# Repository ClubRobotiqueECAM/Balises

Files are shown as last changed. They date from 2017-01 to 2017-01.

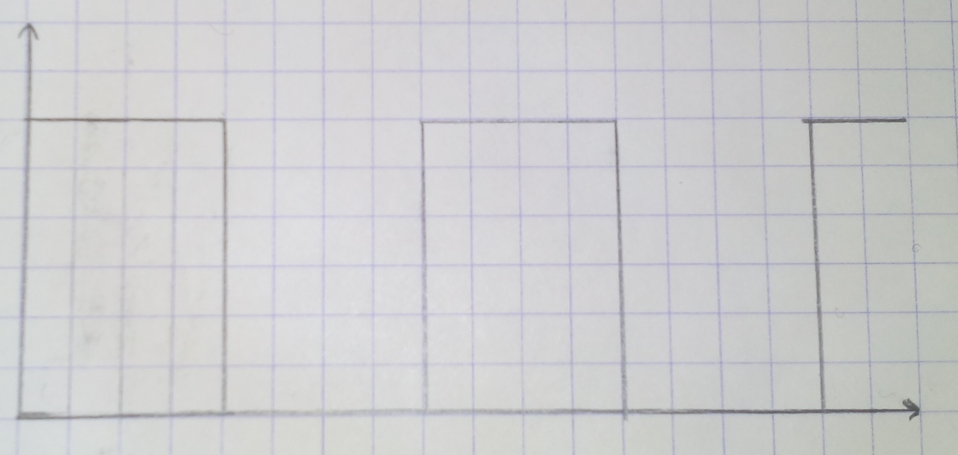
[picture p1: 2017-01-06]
Rapport/Fichiers supports/2015-11-20 09.31.01 mot.jpg

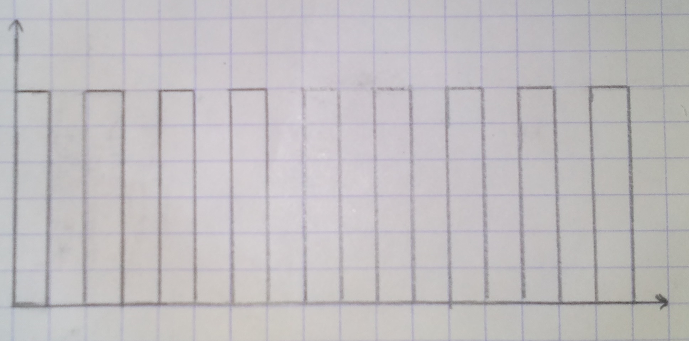
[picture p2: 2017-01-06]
Rapport/Fichiers supports/2015-11-20 09.34.17 porteuse.jpg

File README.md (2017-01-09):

#Balises de positionnement
===========

Projet de recherche et developpement de ma dernière année de l'ECAM. Ce projet est demandé par le club robotique afin de participer à la coupe de france de robotique.

##En résumé :

Le systeme est conposé de 3 balises fixes et d'une balise mobile à positionnée. Avec deux ondes de differentes célérité (Radio fréquence à 2.4GHz et ultrason à 40KHz) nous mesurons la difference de temps pour remonter a la distance.

##Contributing

  * Fork it
  * Create your feature branch (git checkout -b my-new-feature)
  * Commit your changes (git commit -am 'Add some feature')
  * Push to the branch (git push origin my-new-feature)
  * Create new Pull Request

Pour plus d'information rendez-vous dans le dossier "Rapport"

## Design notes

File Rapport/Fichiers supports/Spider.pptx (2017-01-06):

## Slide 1

Capteur
optique

Timer

Précision

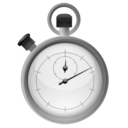
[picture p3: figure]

Durée

Composants haute
qualité

Périodique

Localiser

Récepteur

Etalonnage capteur définitif

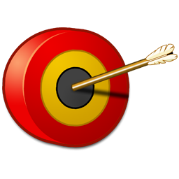
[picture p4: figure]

Distance

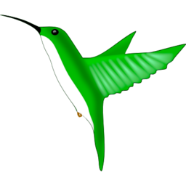
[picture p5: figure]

Pas d’obstacle physique

Pouvoir localiser sur toute la table

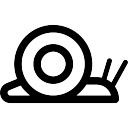
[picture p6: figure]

Calcul embarqué

Réactif

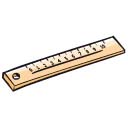
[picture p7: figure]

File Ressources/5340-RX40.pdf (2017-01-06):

# ULTRASONIC TRANSDUCER -RECEIVER

Order Code: MA40A5R

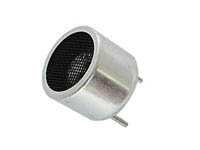
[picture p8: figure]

## Specifications

- description: ultrasonic transducer - receiver
- max. input voltage: 20Vrms
- operating temperature: -20°C to +85°C
- range: 0.2 to 6m
- nominal frequency: 40kHz
- sensitivity: -67dB min.
- sound pressure: 112dB min. •

## Dimensions

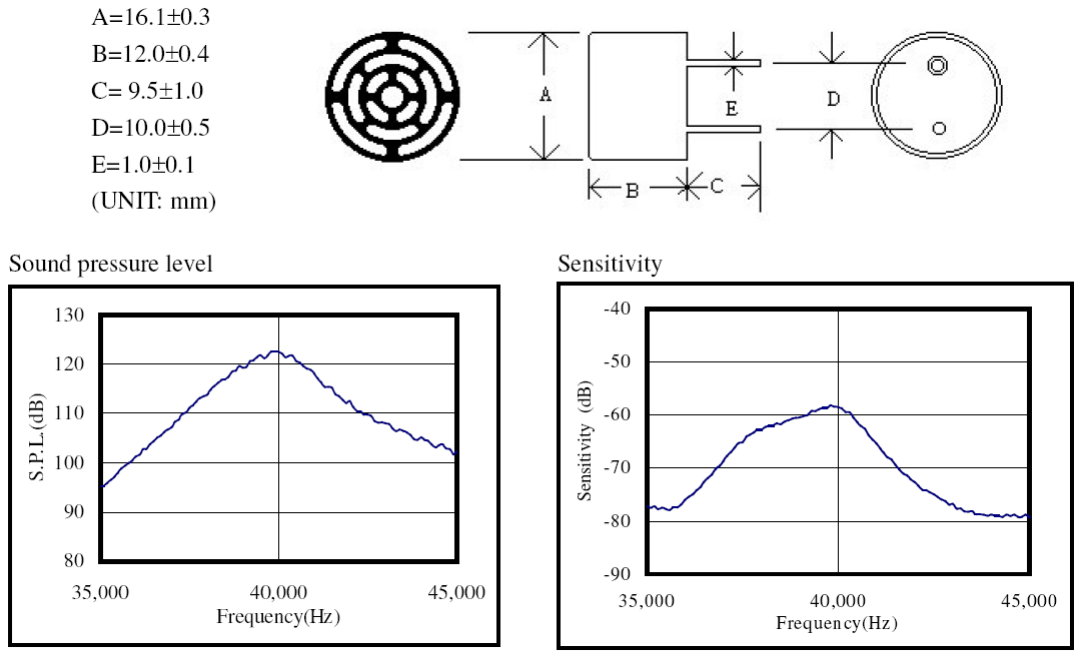
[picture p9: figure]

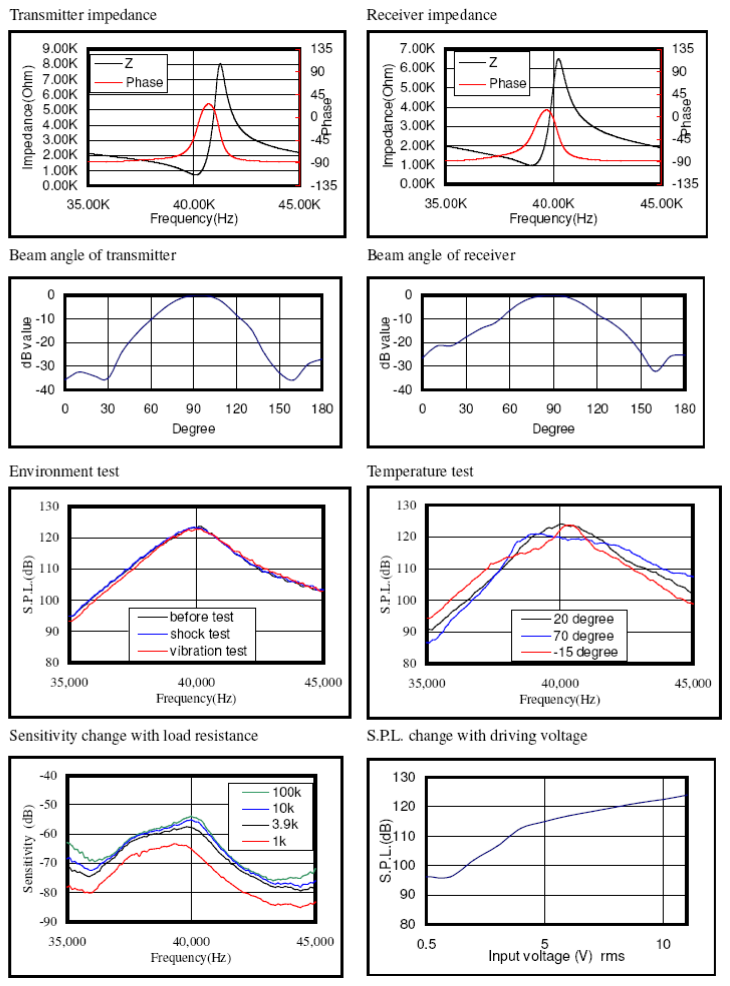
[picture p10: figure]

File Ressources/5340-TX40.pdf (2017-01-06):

# ULTRASONIC TRANSDUCER -TRANSMITTER

Order Code: MA40A5S


## Specifications

- description: ultrasonic transducer - transmitter
- max. input voltage: 20Vrms
- operating temperature: -20°C to +85°C
- range: 0.2 to 6m
- nominal frequency: 40kHz
- sensitivity: -67dB min.
- sound pressure: 112dB min.

## Dimensions

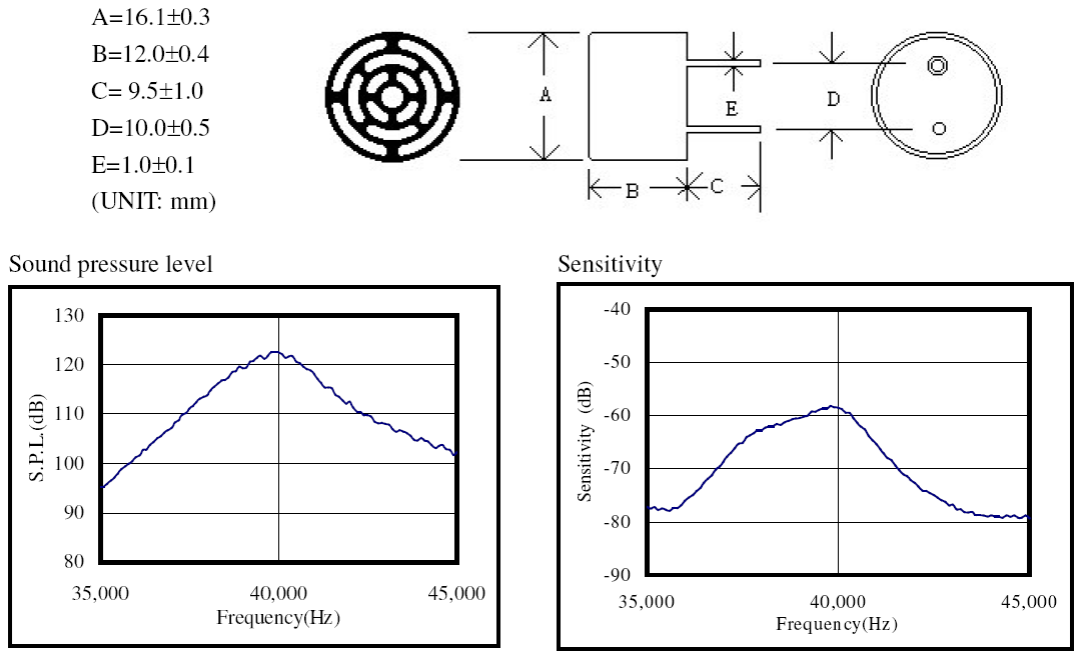
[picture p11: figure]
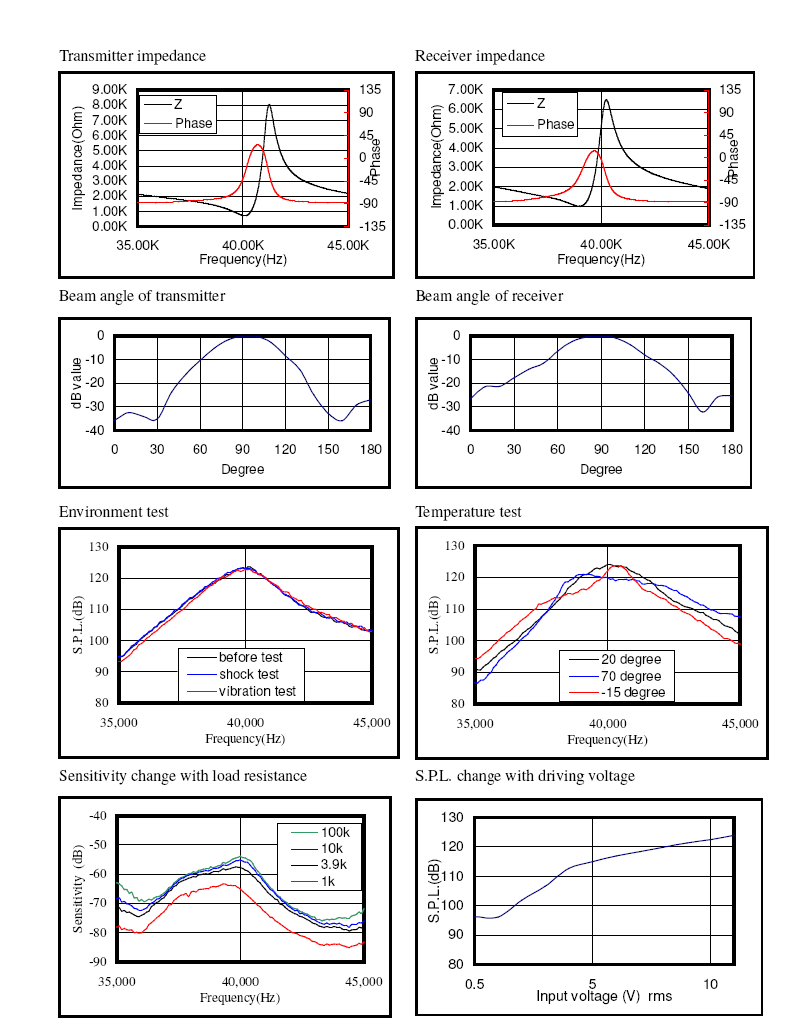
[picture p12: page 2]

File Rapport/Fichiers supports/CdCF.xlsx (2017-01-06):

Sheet: Feuil1
Cahier des charges
Numéro | Fonction | Critères | Niveau | Fléxibilité | check
1 | Permettre aux robots de se localiser sur la table | Ecart en x | +/- 5 cm |  | 1/2
 |  | Ecart en y | +/- 5 cm |  | 1/2
 |  | Fréquence de localisation | 1s |  | 1/2
2 | Fonctionner depuis emplacement présus sur les robots | Nbr de possibilité | 2 (alliée/adverse) |  | 1/0
 |  | Portée réception | 3m
3 | Se Fixer sur les emplacements prévus sur les robots | Type de fixation | amovible |  | 1/0
4 | Fonctionner depuis emplacement présus sur la table | Nbr de possibilité | 1 (3 positions fixes) |  | 2/0
 |  | Portée émission | 3m
5 | Se Fixer sur les emplacements prévus sur la table | Type de fixation | amovible |  | 2/0
6 | Respecter les dimensions imposées (lxLxh) | mobile | 80x80x80 mm |  | 3/0
 |  | fixe | 80x80x160mm |  | 3/0
7 | Respecter le poids imposé | mobile | 400g |  | 3/0
 |  | fixe | 400g |  | 3/0
8 | Ne pas êtres gêné par les perturbations | lumineuse |  |  | 4/0
 |  | sonore |  |  | 4/0
9 | Ne pas êtres perturbé par les balises adverses |  |  |  | 5/0
10 | Ne pas perturber les balises adverses |  |  |  | 0/5
11 | Etres réutilisable | durée de vie | 3 ans min. |  | 6/0
12 | Pouvoir choisir le nom de la balise | Mode de choix | plusieurs possibilité définis à l'avance |  | 7/0
13 | Pouvoir commender le démarrage | type de commande | Interrupteur manuel |  | 7/0
14 | Montrer le nom de la balise | type d'indicateur | visuel |  | 0/7
16 | Etres autonome | Type d'alimentation | battery |  | 0/0
 |  | autonomie | 15 minutes |  | 0/0

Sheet: Feuil2
Cahier des charges
Numéro | Fonction | Critères | Niveau | Fléxibilité | check
 | Localiser la balise mobile avec 3 fixes
 | Communiquer la position/mesure
 | Calculer la position
 | Respecter le volume maximal
 | Respecter le poids maximal
 | Positions imposées dans l'espace des 3 balises fixes
 | Etre auto-alimentée

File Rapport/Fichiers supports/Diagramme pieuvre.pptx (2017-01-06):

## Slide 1

Robots

Table

2

1

Règles de
la coupe

Balises
Autonomes

3

Utilisateur

0

Environnement extérieur

7

4

Club
robotique

Balises
ennemies

6

5

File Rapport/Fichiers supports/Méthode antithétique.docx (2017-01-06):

Méthode antithétique :

Perdre une balise

Cacher Obstacle (Visuel)

Invisible

Cacher parmi d’autre

Cacher dans l’environnement

Masquer son

Silence

Bruit

Pour localiser la balise :

- Visible/regarder
- Différentes des autres (se démarquer)
- Sans obstacle : règlement
- Son particulier / écoute

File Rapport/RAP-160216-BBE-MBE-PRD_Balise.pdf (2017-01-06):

# Balise de localisation pour Robot

## Projet de R&D

Pôle

Recherche et Développement

Auteurs | : Bruno BELLIER, Maxence BEROUJON
Date | : 16/02/2016
Promotion | : 2016

# Informations générales

Auteur(s)

Nom(s) | Bruno BELLIER, Maxence BEROUJON
Promotion | 2016
Formation | ECAM 5

Département

Nom | Pôle Recherche et Développement
Professeur référent | Christophe Jouve

# Sommaire

Introduction | 5
I. Cahier des charges | 6
II. La Créativité | 9
III. Tests et prototypages | 12
IV. Plan Balises | 14
1. | Le système des 4 balises | 15
2. | Principes généraux des balises fixes | 16
3. | Principes généraux de la balise fixe | 17
1. | Le circuit des balises fixes (émettrices US) | 18
1. | Le circuit de la balise mobile (réceptrice US) | 19
1. | Programme pour la balise mobile | 22
2. | Programme pour les balises fixe | 22

## Introduction

Dans le cadre de notre formation à l’ECAM Lyon, nous avons travaillé deux jours par semaine lors de notre dernier semestre de cours sur un Projet de Recherche et Développement. Ce dernier est particulier car il est financé et demandé par le Club robotique de l’ECAM.

Le binôme est constitué de Maxence Beroujon et Bruno Bellier. Pour nous aider les professeurs, le personnel et le matériel de l’ECAM ont été mis à notre disposition. Le Club robotique est une association d’élèves qui partagent la passion, ou qui veulent découvrir des connaissances en robotique. En mécanique de petit système, modélisation, électronique, et programmation. Depuis déjà 3 ans le club participe à la coupe de France de robotique. Cet évènement rassemble des étudiants qui ont la passion de la robotique, et il permet le challenge entre école. Le principe : 2 équipes s’affrontent sur la table. Elles ont pour but de faire le maximum de points. Chaque équipe est constituée de deux robots maximum.

Lors de cette coupe, les robots n’ont pas le droit d’être en contact. Et les robots doivent connaitre leur position pour faire des actions avec précision. C’est là que le projet intervient.

Grâce à nous les robots ECAM peuvent soit connaitre la position de l’adversaire, soit connaitre avec précision sa position.

Ce dossier retrace la démarche suivis lors du projet, c’est pourquoi il y a une évolution dans les choix technique au cours du dossier. Nous espérons que ce dossier vous sera utile pour comprendre ce qui nous a permis de faire nos choix, afin de modifier, améliorer, ou refaire les balises.

## I. Cahier des charges

## A. Cahier des charges initial

Afin de fixer des premières directions sur lesquelles s’engager, et de répondre aux exigences du club robotique de l’ECAM, nous avons élaboré un premier jet du cahier des charges, comprenant les fonctions principales du produit à réaliser. Ce document était principalement issu des règles de la coupe de France de robotique.

Le projet consiste donc à concevoir et réaliser un système de balises à placer sur le robot et sur le terrain de manière à pouvoir localiser le robot où qu’il soit sur la table.

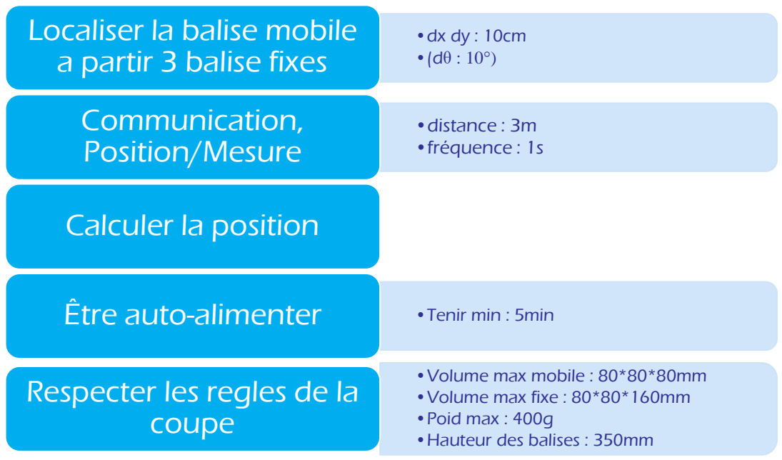
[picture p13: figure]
Localiser la balise mobile a partir 3 balise fixes; •distance : 3m •fréquence : 1s; Communication, Position/Mesure; Calculer la position; Être auto-alimenter; •Tenir min : 5min; •Volume max mobile : 80*80*80mm •Volume max fixe : 80*80*160mm •Poid max : 400g •Hauteur des balises : 350mm; Respecter les regles de la coupe

## B. Le diagramme pieuvre

Afin d’élaborer un cahier des charges complet et de s’approprier pleinement le sujet nous avons réalisé un diagramme pieuvre sur la phase de vie clé du produit qui est, dans notre cas, sa phase d’utilisation :

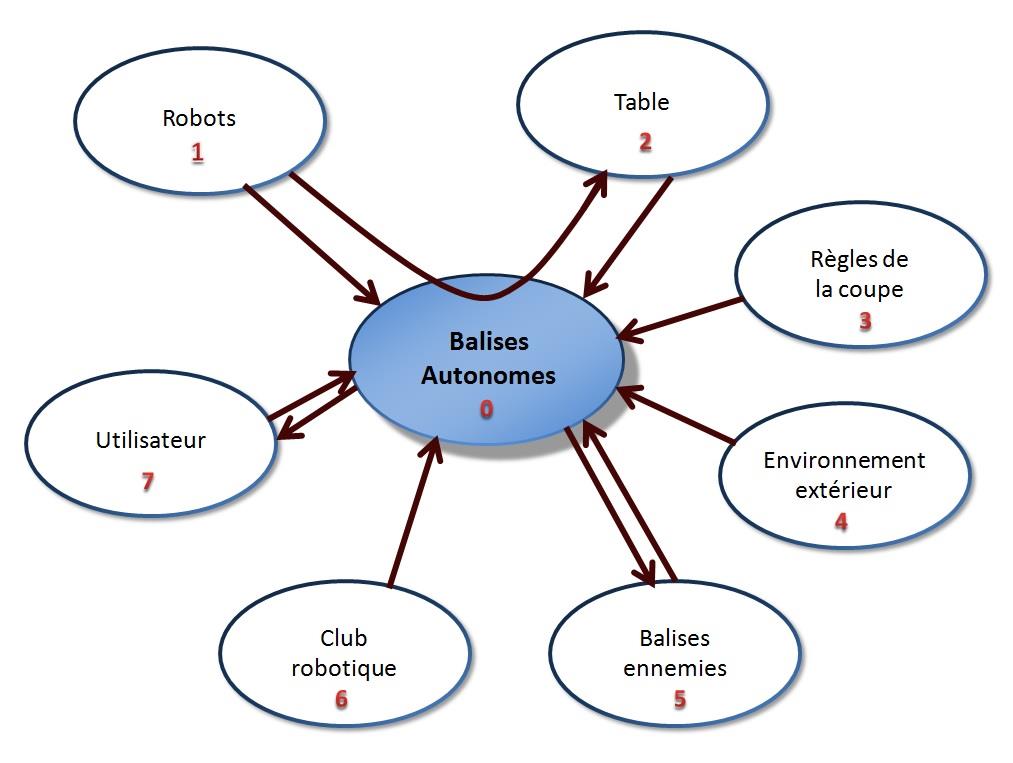
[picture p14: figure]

De ce diagramme pieuvre, on ressort différentes fonctions :

Fonction principale :

1→2 : Permettre aux robots de se localiser sur la table

Fonctions contraintes :

1→0 : - Fonctionner depuis emplacements prévus sur les robots
- Se fixer sur les emplacements prévus sur les robots

2→0 : - Fonctionner depuis emplacements prévus sur la table
- Se fixer sur les emplacements prévus sur la table

3→0 : - Respecter les dimensions imposées
- Respecter le poids imposé

4→0 : - Ne pas être gêné par les perturbations lumineuses (présentes lors de la compétition)
- Ne pas être gêné par les perturbations sonores (présentes lors de la compétition)

5→0 : - Ne pas être perturbé par les balises adverses

0→5 : - Ne pas perturber les balises adverses (volontairement)

6→0 : - Posséder une documentation complète et compréhensible de la partie programme
- Posséder une documentation complète et compréhensible de la partie physique
- Etres réutilisable et modifiable par le club dans l’avenir

7→0 : - Pouvoir choisir le nom de la balise
- Pouvoir commander le démarrage (même si l’alimentation est déjà faite)

0→7 : - Montrer à l’utilisateur le nom de la balise

0 : - Etre autonome en alimentation

## C. Cahier des charges fonctionnelles

Grâce aux outils précédents, nous avons pu réaliser un cahier des charges fonctionnelles auquel se référer durant le projet.
N° | Fonction | Critères | Niveau | Flexibilité | check
1 | Permettre aux robots de se localiser sur la table | Ecart en x | +/- 5 cm | | 1/2
| | Ecart en y | +/- 5 cm | | 1/2
| | Fréquence de localisation | 1s | | 1/2
2 | Fonctionner depuis emplacement prévus sur les robots | Nbr de possibilité | 2 (alliée/adverse) | | 1/0
| | Portée réception | 3m
3 | Se Fixer sur les emplacements prévus sur les robots | Type de fixation | amovible | | 1/0
4 | Fonctionner depuis emplacement prévus sur la table | Nbr de possibilité | 1 (3 positions fixes) | | 2/0
| | Portée émission | 3m
5 | Se Fixer sur les emplacements prévus sur la table | Type de fixation | amovible | | 2/0
6 | Respecter les dimensions imposées (lxLxh) | mobile | 80x80x80 mm | | 3/0
| | fixe | 80x80x160mm | | 3/0
7 | Respecter le poids imposé | mobile | 400g | | 3/0
| | fixe | 400g | | 3/0
8 | Ne pas être gêné par les perturbations | lumineuse | | | 4/0
| | sonore | | | 4/0
9 | Ne pas être perturbé par les balises adverses | | | | 5/0
10 | Ne pas perturber les balises adverses | | | | 0/5
11 | Etres réutilisable | durée de vie | 3 ans min. | | 6/0
12 | Pouvoir choisir le nom de la balise | Mode de choix | plusieurs possibilités définis à l'avance | | 7/0
13 | Pouvoir commander le démarrage | type de commande | Interrupteur manuel | | 7/0
14 | Montrer le nom de la balise | type d'indicateur | visuel | | 0/7
16 | Etres autonome | Type d'alimentation | batterie | | 0/0
| | autonomie | 15 minutes | | 0/0

## II. La Créativité

Une fois que nous avons déterminé les bases du projet, nous avons réfléchi aux différentes manières de répondre au cahier des charges. Pour cela nous avons réalisé une séance de créativité au cours de laquelle nous avons utilisé plusieurs méthodes.

## A. Réflexion antithétique

De manière à trouver des méthodes pour répondre aux fonctions, nous avons utilisé une réflexion antithétique. Cette méthode consiste à trouver toutes les manières de ne pas réaliser la fonction étudié afin de mettre en évidence tout ce qui est nécessaire et tout ce qui peut permettre de réaliser la fonction étudié.

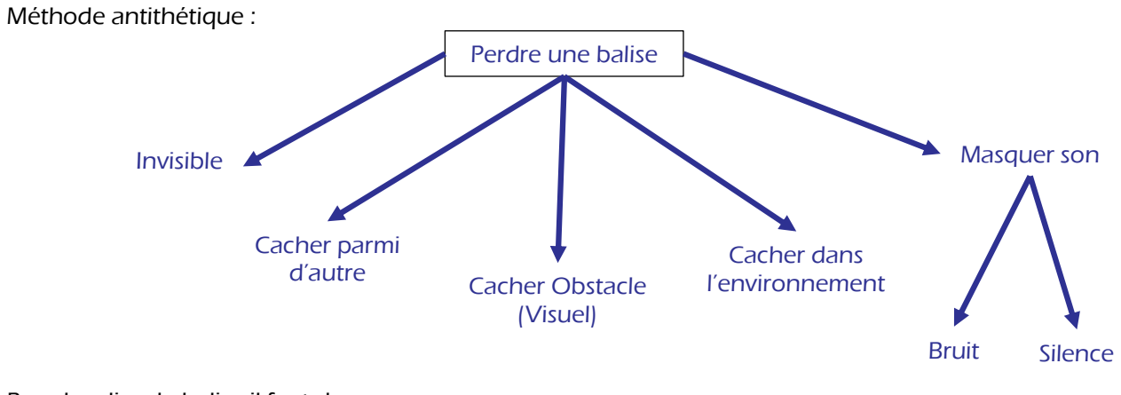
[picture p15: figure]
Méthode antithétique :; Perdre une balise; Cacher Obstacle (Visuel); Invisible; Cacher parmi d’autre; Cacher dans l’environnement; Masquer son; Bruit; Silence

Pour localiser la balise il faut donc:

- Etre visible/regarder
- Etre différentes des autres (se démarquer)
- Ne pas avoir d’obstacle : imposé par le règlement
- Emettre un son particulier / écouter

## B. Localiser un objet (Spider)

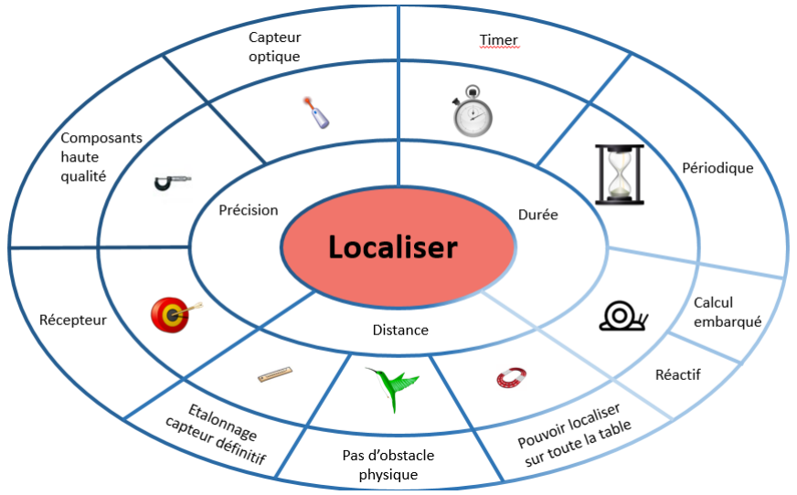
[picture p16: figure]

De ce spider, on ressort différente idées :

Le choix de capteur pour la réalisation de notre projet nous a semblé évident.

En, effet, les capteurs optiques nous semblaient être le moyen d’obtenir le plus de précision. Nous avons cependant étudié d’autres capteurs, comme les capteurs ultrasons, qui ne nous ont pas autant séduits.

Le règlement de la coupe de France de robotique impose les dimensions de la table, de ses décorations, ainsi que des robots, nous sommes donc assurés de ne pas avoir d’obstacle entre nos balises. Le robot se déplaçant sur l’intégralité de la table, nous devons pouvoir le localiser sur l’intégralité de la table.

Le robot étant en mouvement permanent, le système doit être réactif, la localisation doit donc s’effectuer rapidement. Nous avons décidé de faire l’ensemble des calculs de localisation dans la balise de réception (de manière embarqué), ainsi les seules informations transmises au robot sont ses coordonnées. Les mesures et calculs de localisation sont évidemment faits de manière périodique.

L’idée du timer (chronomètre) a été prise en compte dans notre solution par le fait que l’on utilise l’horloge interne de l’Arduino pour réaliser nos calculs.

Nous avons choisi d’effectuer un étalonnage des capteurs de façon définitive tant que l’on ne change pas d'environnement.

La volonté d’utiliser des composants de haute qualité n’a finalement pas été retenue afin de pouvoir épargner autant que possible le budget du club robot, donc d’avoir un budget PRD le plus faible possible tout en respectant nos critères de fonction.

## C. Calcul de position

Pour calculer la position du robot depuis les trois balises fixes, nous avons pensé à trois méthodes de calcul.

La première consiste à relever l’angle et la distance (couleur bleue et rouge figure1) entre chaque balise et le robot, pour avoir la position de ce dernier en coordonnées polaires. Ce qui nous amène à avoir une balise qui localise et deux balises qui vérifient cette localisation.

La deuxième consiste à mesurer seulement l’angle (en bleu) pour chaque balise. Mais après s’être renseigné un peu sur le sujet et y avoir réfléchi un certain temps. Nous nous sommes rendu compte que les mesures d’angle que l’on pouvait effectuer par cette méthode demeuraient très approximatives et ne permettaient donc pas d’obtenir la précision voulue.

Enfin, la troisième méthode permet de localiser le robot en mesurant les distances entre chaque balise et le robot. Cette méthode s’avère être la plus répandue et permet d’obtenir la plus grande précision quelle que soit la distance entre les balises et le robot. C’est finalement à partir de cette méthode de calculs, que nous avons basé notre réflexion.

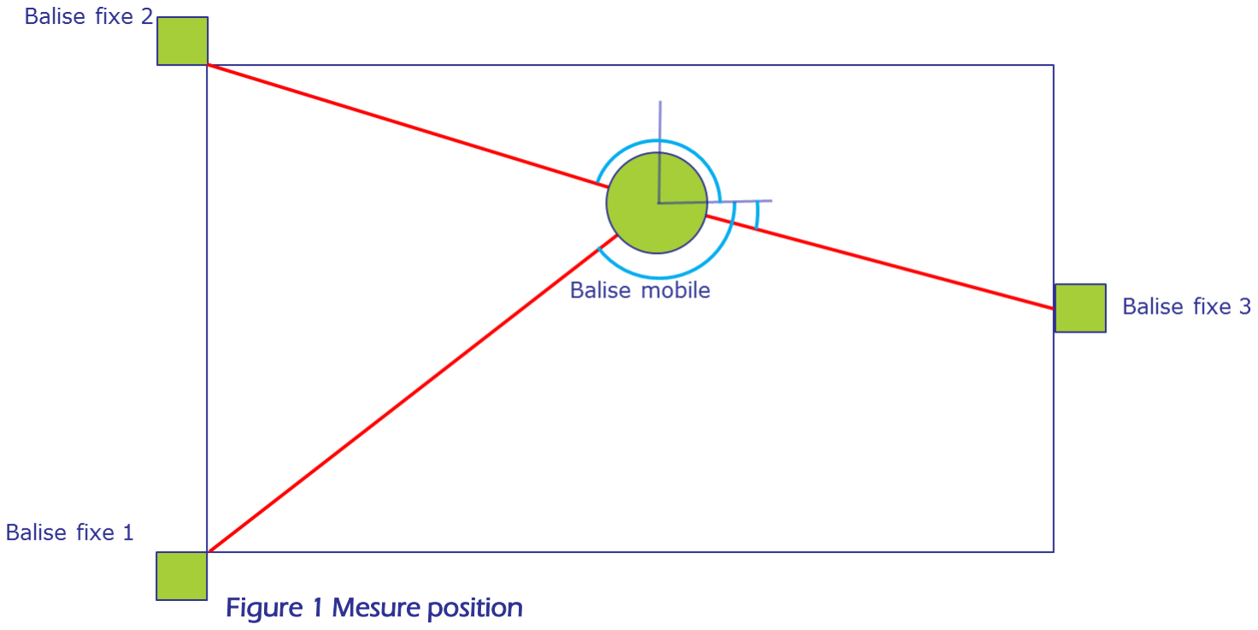
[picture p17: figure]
Figure 1 Mesure position

## D. Étude de 2 systèmes de mesure de distance existant

Après réflexion, nous nous sommes attardés sur deux types de capteurs afin d’effectuer nos mesures, à savoir, les capteurs infrarouges et les capteurs ultrasons.

Le capteur infrarouge possède une bonne plage de fréquence sur laquelle il est possible de travailler grâce à des émetteurs répartis sur cette plage. En revanche le champ d’action des capteurs est focalisé sur une seule direction avec un débattement de seulement 10° de chaque côté. De plus ils peuvent être rapidement perturbés par des sources lumineuses ou d’autres capteurs infrarouges. Or, lors de la coupe de France de robotique il existe beaucoup de perturbation de ce type. En effet, les spots émettent des infrarouges, et les balises adverses sont, d’après nos recherches, essentiellement basés sur un système infrarouge. Enfin, l’utilisation d’infrarouge est souvent employée pour des mesures d’angle (dans les cas de localisation par balises) et la localisation reste souvent très approximative.

L’ultrason travaille sur une plage de fréquence plus restreinte que l’infrarouge et les capteurs que nous avonstrouvés en vente ne travaillent que sur deux fréquences différentes 40 kHz ou 58kHz. En revanche, les capteurs permettent une diffusion plus large du signal (60° centré sur une direction). Les sources de perturbation sont la température et les autres sources d’ultrason. Cependant, la température ne fait varier que la vitesse de propagation des ultrasons, et dépend d’une formule. C’est donc une perturbation dont nous pouvons tenir compte dans les calculs. Par ailleurs, nous avons remarqué les ultrasons étaient très peu utilisés lors de la coupe de France de robotique. Enfin des résultats nous ont montrés que des mesures par ultrasons pouvait nous permettre d’être précis jusqu’au centimètre, ce qui nous permettrait de largement respecter le critère de précision de notre cahier des charges fonctionnel.

Au fait des résultats de ces recherches, nous avons décidé de baser notre projet sur l’utilisation des ultrasons.

## E. Analyse : sélection de HF+US

Tous les dispositifs que nous avons trouvés pour mesurer des distances à l’aide d’ultrasons étaient basés sur un principe d’aller-retour. Il est donc question d’une mesure de distance par rapport à un obstacle alors que nous souhaitions mesurer une distance par un barrage. Pour pouvoir effectuer une mesure directe entre deux points, nous avons alors utilisé une méthode permettant de s’affranchir de la fonction aller-retour classique. Ce principe sera peut-être à remettre en question dans les améliorations futures.

Cette méthode consiste à utiliser des ondes radios en guise de référence. Il s’agit d’émettre simultanément une onde HF (haute fréquence) et une onde US (ultrasonique). Les ondes HF sont des ondes « lumière » alors que les ondes US sont des ondes « son », ce qui modifie littéralement leur vitesse de propagation. Si on émet en même temps ces deux types d’ondes, les ondes HF arriveront bien plus vite que les ondes US. L’onde HF met 10ns pour parcourir 3m alors que les US met 8,8ms, on peut alors faire l’hypothèse que l’onde HF arrive instantanément et nous donne donc l’heure d’émission de l’onde US. Cette hypothèse engendre une erreur d’un nanomètre sur la mesure. Connaissant la vitesse et le temps entre l’émission et la réception, on peut alors trouver la distance entre l’émetteur et le récepteur.

Nous avons trouvé cette méthode ici. (http://em6.club.resel.fr/coupe_2003/coupe_2002/site%202001/anciens/balises1999.php3)

## III. Tests et prototypages

Cette partie survole nos étapes de prototypage. Cela vous servira d’exemple pour vos projets futurs, ou de contre-exemple. :D

## A. Emission continue

Pour la phase de conception électronique, nous avons trouvé la
datasheet | des | émetteurs | et | des
récepteurs que le club possède. Ce qui nous a donné un modèle, nous avons ensuite construit les circuitsfonction par fonction pour les tester au fur et à mesure. En premier lieu, le générateur de 40kHz en 0-10v puis la double amplitude centrée, -10v;10v pour le circuit émetteur.

Après nous avons construit le circuit de réception avec un aop en montage non-inverseur. Sur l'entrée +, il y a la
fonction | sommateur, | ainsi | qu'un
condensateur de lissage des pic. Le signal ce vois donc osciller, centrée sur le (5V).

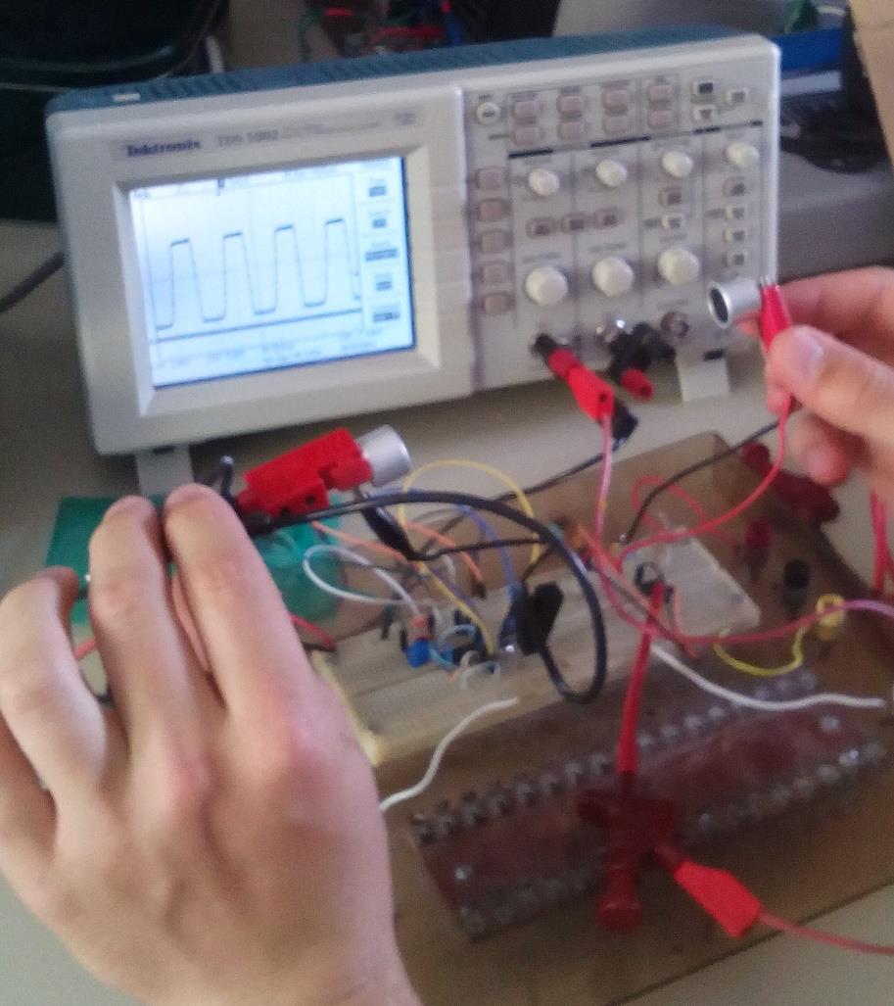
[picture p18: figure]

Avec les succès de ces deux parties, la liaison ultrason est assurée.

## B. Emission de 1110

Pour être sûr que les ultrasons captés proviennent bien de nos balises, des mots binaires sont insérés. Nous avons fait nos premiers tests avec un mot simple 1110.

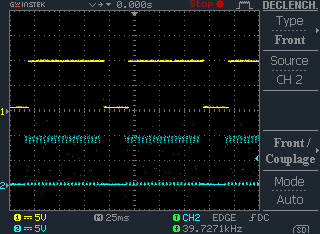
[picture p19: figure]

## C. Emission Serial puis Série de nous

Dans un premier temps nous avons utilisé le Sérial pour générer un mot, mais nous n’étions pas synchronisé, la réception n’arrivait pas à reconnaitre le début de la transmission. Nous avons opté pour la création d’un protocole de communication série unifilaire et unidirectionnel. Nous avons conservé ce mode de transmissions c’est pourquoi il sera développé ici.

## D. Emission HF

Grâce au projet léonard objet ludo-pédagogique, nous avons rapidement trouvé la référence, et la bibliothèque pour faire fonction la communication Haute fréquence. Avec une lecture approfondie des méthodes interne, nous remarquons que cette bibliothèque est faite pour une communication entre deux éléments. Le module quant à lui permet une réception en provenance de 5 adresses simultanément. Nous avons donc modifié la librairie.

## E. Emission HF+US

Une fois nos deux communications testées séparément, nous mettons en commun les programmes et les circuits pour former un prototype complet. Pour savoir si les communications fonctionnent correctement, la réception US attend un signal HF pour écoute les mots.

Avec un seul émetteur et un récepteur, nous avons obtenu de bons résultats à courte, moyenne et grande distances. Nous avons d’ailleurs fait une courbe pour voir si les résultats obtenu étaient une fonction simple de la distance ou pas. En l’occurrence, nous avons trouvé une fonction linéaire.

## F. Du prototypage à la réalisation

Pour des questions de cout et délai nous avons réalisé au club les cartes électroniques. Dans les différents dossiers

## IV. Plan Balises

Vous voici enfin dans la partie intéressante : Nous allons dévoiler tous les secrets des balises. Nous allons faire la présentation en pyramides : en premiers les concepts théorique, puis une vue d’ensemble, et enfin un détail technique le plus claire possible. Pour être sûr que vous vous rappelez de tout ce qui a été dit plus haut comme des solutions possible, nous n’avons pas hésitez à réécrire les éléments importants.

## A. Principes généraux

Les balises fonctionnent sur le principe du GPS : la mesure du temps de propagation à vitesse constante permet de déterminer une distance. Un GPS est à l’heure juste, dans la tram du signal il envoie l’heure d’émission et quand le GPS reçoit il calcul le temps puis la distance.

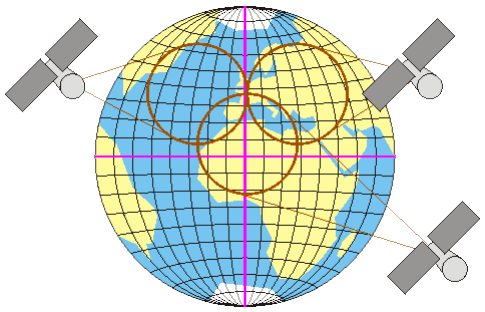
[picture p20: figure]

Sur une distance approximative de 20 000km à la vitesse de la lumière, le signal GPS met environ 66ms. Compte tenu de nos distance minuscules par rapport à celle mesurées par GPS nous avons opté pour l’émission d’onde ultrasonique US (8,8 ms pour 3m). Sauf que la célérité (c en m.s⁻¹
) du son est une
fonction de la température, θ en °C.

cair = (331.5 + 0.607 ∗ θ) m. s

−1

Cette approximation est valable sur des températures usuelles (-20 ; +40) avec une incertitude inférieure à 0.2%.

Pour la mesure du temps il faut une synchronisation. Dans le cas du GPS elle est faite au moment de l’envoie du satellite. C’est ici que nous avons besoin des ondes hautes fréquences HF (onde électromagnétique). (https://fr.wikipedia.org/wiki/Spectre_%C3%A9lectromagn%C3%A9tique) Ces dernières sont des ondes électromagnétique comme la lumière, et se propage à la même vitesse soit 299 792 458 m.s⁻¹
. Le temps de propagation de l’onde HF ajoute une erreur de 1µm sur la mesure donc nous négligeons de temps par rapport à la propagation de l’ultrason.

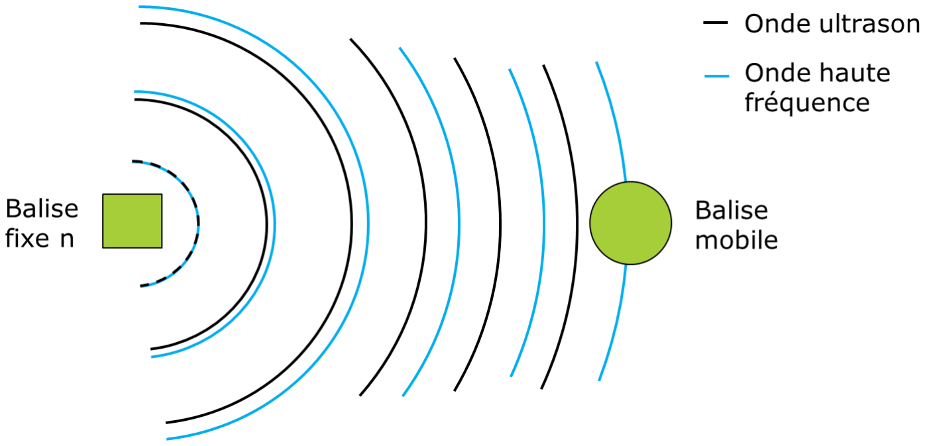
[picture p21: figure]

### 1. Le système des 4 balises

Pour se resituer, nous avons donc 4 balises, 1 de type Mobile, et 3 du type Fixe. Nous cherchons la position de la Mobile par rapport au 3 fixes.

a) Mesure et Calculs

Pour mesurer la distance, nous relevons l’heure d’arrivée du message HF, puis l’heure de réception du « start » du message US. On divise ensuite la durée, la différence entre les deux heures d’arrivée, par la vitesse du son afin d’obtenir la distance

Pour ensuite calculer les coordonnées de la balise mobile, on a obtenu une formule en partant du système suivant :{

d1

2 = (0 − x)
2 + (0 − y)

2
d2

2 = (0 − x)
2 + (200 −y)

2
d3

2 = (300 − x)
2 + (100 −y)

2

Où d1, d2 et d3 sont respectivement les distances mesurées avec la balise fixe 1, la 2 et la 3.

Pour obtenir les formules que l’on utilise :x =

0.5d1

2+0.5d2

2−d3

2+80 000

600

## et y =

d1

2−d2

2+40 000

400
Toutes les valeurs dans, et calculées avec, cette formule sont en centimètre.

Pour tester vos formule visuellement vous pouvez utilise cette application web ici (https://app.geogebra.org/) avec le fichier geogebra.ggb dans le dossier Ressources.

b) Communication entre les balises

Pour simplifier les explications, les balises fixes seront appelées BF1-3, et la balise mobile BM

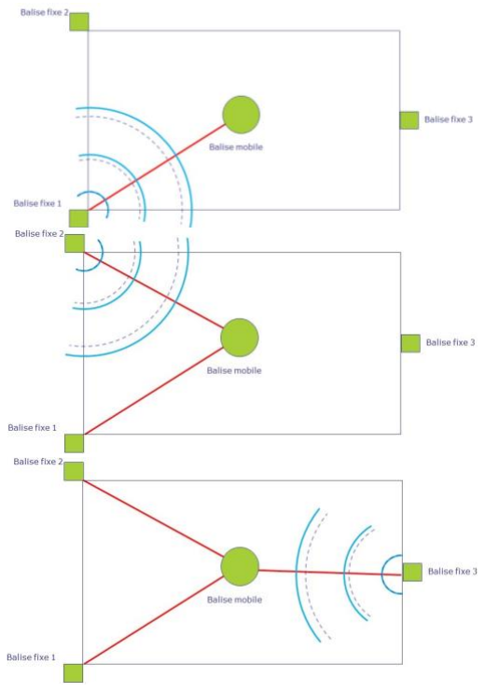
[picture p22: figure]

BF 1 Envoie son message en HF et US pour que BM puisse mesurer la 1° distance. (1°à gauche)

BF1 envoie un top à BF2. (1°à droite)

À la réception du top BF 2 envoie son message en HF et US pour que BM puisse mesurer la 2° distance. (2°à gauche)

BF2 envoie un top à BF3. (2°à droite)

À la réception du top BF 3 envoie son message en HF et US pour que BM puisse mesurer la 3° distance. (3°à gauche)

BF3 envoie un top à BF1. (3°à droite) Cela boucle jusqu’à l’arrêt des balises.

Nous avons fait une animation pour visualiser les communications : dans le dossier "Fichiers supports".

### 2. Principes généraux des balises fixes

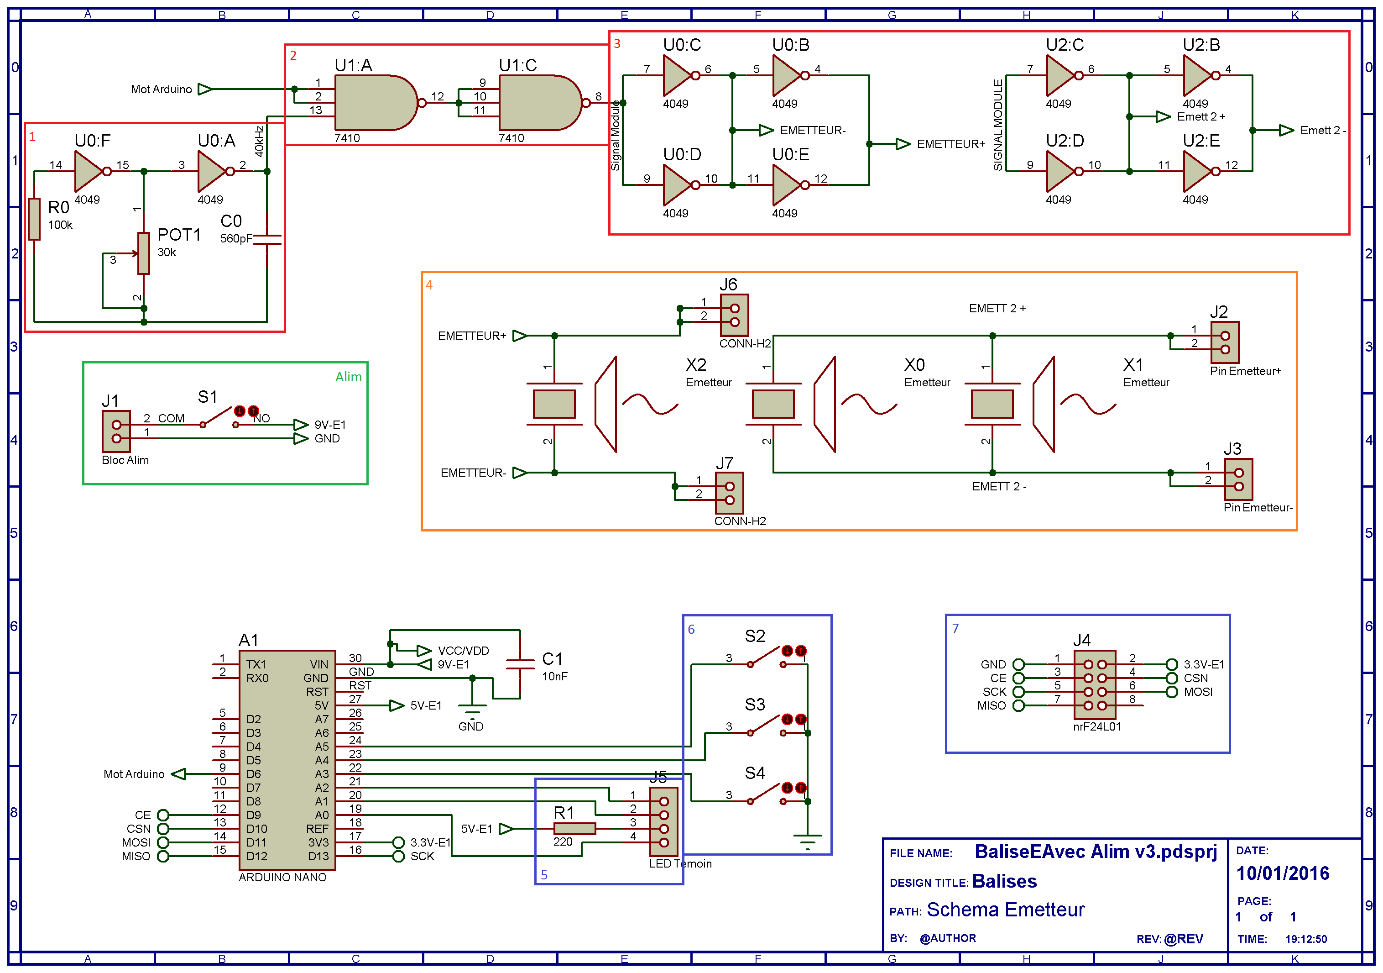
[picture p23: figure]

La carte électronique de BF sert principalement à multiplexer le mot et la fréquence de l’ultrason. Elle constitue aussi l’interface entre Arduino nano, émetteur US, module HF et nous les humains.

Si vous ne trouvez pas que les cartes électronique sont les trois mêmes c’est vrai le U2 a été rajouté que sur 2 cartes car elle manquait de puissance.

L’encadré 4 schématise le branchement en parallèle des émetteurs. Il n’y a pas plus de 2 composants sur une porte logique. Il Nous allons détailler les encadrés Rouge et Bleu.

L’algorithme des BF est linéaire. Grâce aux boutons il faut choisir l’idBalise. Cet id permet de changer les mots transmis, et le mot attendu pour le top. Chaque id correspond à une couleur de la LED pour visuellement

Grace au système d’id, le programme des 3 BF est le même.

Tant qu’elle fonctionne, la balise reste dans la boucle. Je laisse l’image parlée

Entre Chaque étape il y a des temporisations. Pour optimiser le temps de

Oui

Non

### nbDistanc

e=3

## CalculerPosition

Oui

Non

MotHF=
MotUS

## CalculerDistance

# Boucle

## ReceptionHF

## ReceptionUS

## EnregistrerLaDate

### 3. Principes généraux de la balise fixe

La carte électronique de BM est aussi une interface mais seulement entre Arduino, récepteurs US et module HF. L’interface homme-balise est faite via le port USB de l’Arduino uniquement.

Sur le schéma seul deux récepteurs (X1 et X2) sont symbolisés mais il y en a 6 dans la réalité. Le signal est capté par X1-6. Apres traitement, en 6, nous retrouvons le signal en créneaux de mot émis. Dans l’encadré 1 le câblage des récepteurs : une patte a la masse et l’autre a des point différents du circuit pour faire la somme. Les Encadrés Rouge seront détaillés dans une partie dédiée.

Pour l’algorithme ci-contre, la boucle est encore une boucle infini dans la limite de l’alimentation.

Les décisions serves à éviter du calcul sur des mauvaises valeurs. Pour obtenir plus rapidement une position, il possible de diminuer à 2 distances pour une position.

## B. Electronique

### 1. Le circuit des balises fixes (émettrices US)

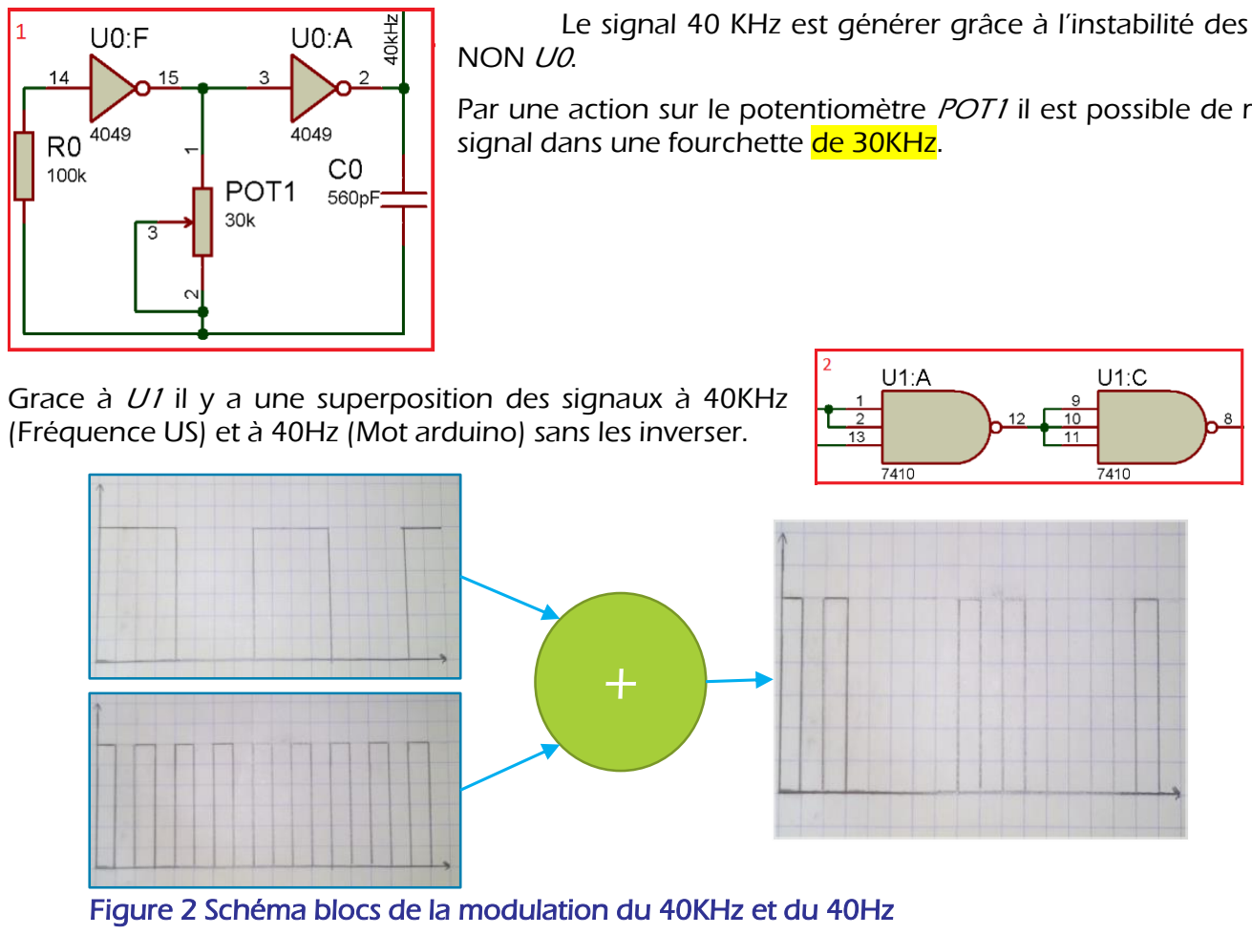
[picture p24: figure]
NON U0.; signal dans une fourchette de 30KHz.

Le signal 40 KHz est générer grâce à l’instabilité des portes

Par une action sur le potentiomètre POT1 il est possible de réglé le

Grace à U1 il y a une superposition des signaux à 40KHz (Fréquence US) et à 40Hz (Mot arduino) sans les inverser.

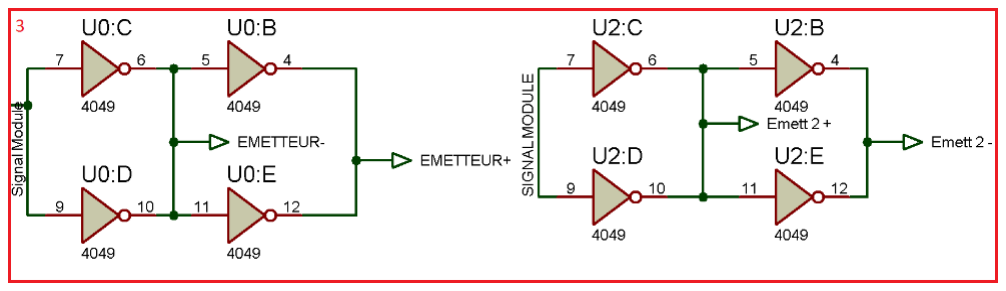
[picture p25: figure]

Cette partie du circuit transforme l’amplitude 0/10V en -10V/+10V

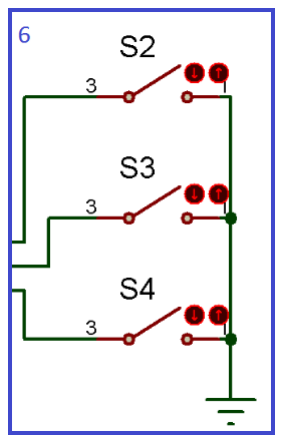
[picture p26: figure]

Une partie interface homme machine pour debug et pour choisir l’identifiant par les boutons S2-4 et une LED RGB. Les interrupteurs doivent être déclarés dans le programme en Pull-Up. Quand on appuis sur le bouton l’entrée passe donc à LOW.

Pour la LED, La commande se fait par des LOW aussi. Par contre par manque de place nous n’avons mis qu’une résistance pour les 3 couleurs donc si vous voulez allumer plusieurs couleurs, faites un test simple au début pour voir la réaction de la LED.


La partie 7 est simplement le câblage du module HF

Figure 2 Schéma blocs de la modulation du 40KHz et du 40Hz

### 1. Le circuit de la balise mobile (réceptrice US)


La zone2 est la plus compliquée car il y a 3 fonction relativement peu sécable : il n’est pas possible de les mesurés séparément. Le composant X1 est le recepteur. Si vous le branchez tel quel à un


oscilloscope, vous obtenez l’écran ci-dessus. Il génère une tension alternative lors qu’il reçoit des ultrasons, d’environ 40mV. L’ensemble {Xi , C1i , R1i , R2i } est reproduit pour chaque récepteur. Afin de couvrir les 360°, il est réalisé 6 fois. Cet ensemble avec R1 et U10:B constitue un montage sommateur inverseur amplificateur. Qui répond a l’équation : (cf ici) (http://www.elektronique.fr/cours/AOP/aop-amplificateur-sommateur.php)

Vs = −(V1 ∗ (
R1
R11

) + V2 ∗ (

R1
R12

) + V3 ∗ (

R1
R13

) + V4 ∗ (

R1
R14

) +V5 ∗ (

R1
R15

) + V6 ∗ (

R1
R16

))

Or R11 = R12 = R13 = R14 = R15 = R16 = 1KΩ et R1 = 22KΩ donc :

Vs = −22 ∗ (V1 +V2 + V3 + V4 + V5 + V6

)

En conclusion, la sortie est la somme des tensions amplifiée 22 fois. Notre amplificateur étant alimenté par du +9V, 0V il ne peut pas produire une sortie négative. Pour pallier cette difficulté, nous avons rajouté une tension continu de 4,5V avec l’ensemble {R6 , R7 }. La sortie finale doit donc ressembler à cela :


U10:A est branché en montage amplificateur (http://www.elektronique.fr/cours/AOP/aop-montages-de-base.php#aop_1-02) le sortie respecte donc l’équation :

Vs = V+ × (1 +

R2
R3

) = V+ × 101


Pour affecter ce coefficient sur la composante variable et pas sur la composante continue, nous avons rajouté C2 . À droite, voici une copie d’écran de la sortie.

Dans cette section le signal traverse un filtre passe haut qui supprime les fréquence inferieure à fc . La principale composante supprimée sera celle continue. Ainsi nous avons un signal alternatif. Centré sur le 0 comme à la sortie de X1 Mais amplifié.

fc =

1
2πR8C4

= 29,5Hz

Dans la section 5, D1 laisse passer uniquement l’enveloppe du 40KHz à cause de son temps de polarisation. Pour que la diode fonctionne bien il faut la
polarisé grâce à C1 et R4. À
la sortie de cette partie,
nous | retrouvons | en
théorie le mot transmis par ultrason. Ci-dessous voici une capture du signal :


Cette dernière étape
transforme les pseudos front de l’étape précédente en vrai front exploitable par l’Arduino. Le seuil est réglable car il dépend de l’électronique et de leurs défauts.


## C. Mécanique

Pour respecter les dimensions on assemble les balises dans des plaques de 8 cm x 8 cm. On assemble en couche (de bas en haut) :

- (une deuxième plaque pour la balise mobile, pour pouvoir accueillir une balise sur elle, si elle est installée sur notre robot)
- carte électronique
- entretoise de hauteur suffisante pour placer une pile 9V


- plaque séparant les supports du reste (pour guider un peu les US, servir de support pour les piles)
- support avec émetteur (ou récepteur)
- plaque (pour fixer scratch)

Les supports sont issus d’une même pièce paramétrable, bien qu’ils existent en pièces séparées, car il fallait différend fichier pour les imprimer en 3D. Les supports sont composés des mêmes pièces, une dessus et une
dessous, il n’y a pas de sens, juste un nombre
d’émetteur. Les émetteurs ont un champ d’action à


pleine puissance d’émission (de réception pour les récepteurs) de 60°, 30 ° de chaque côté de leur axe. Donc les supports 180° et 360° maintiennent les émetteurs/récepteurs à 60° les uns des autres pour avoir une pleine puissance n’importe où. Pour des raisons de placement des vis pour l’assemblage des supports à 90°, les émetteurs ne sont écartés que de 45°, mais on conserve l’idée de pleine puissance dans toute la direction souhaitée pour les balises d’angle.

## D. Structure de communication

Le principe de communication entre les différentes balises est cyclique. Nous en avons parlé brièvement dans les principes généraux. Ici il va être décortiqué en détail.

On commence avec BF 1. Deux évènements peuvent provoquer la sortie de l’attente:

- Un timeout,
- La réception du signal de BF 3 (signal que l’on évoquera plus tard)

Ensuite BF 1 émet un mot en haute fréquence pour BM. Après une temporisation, BF 1 émet le même mot en ultrason. Après une seconde temporisation, BF 1 émet un signal pour la BF 2. Elle retourne à l’état d’attente.

Et c’est au tour de la balise n°2 de réaliser le cycle, et ainsi de suite.

BM attend d’entendre un mot en haute fréquence. Quand elle le reçoit, elle se met à écouter les ultrasons qu’elle reçoit. Une fois le mot ultrason reçu et reconnu, ou un certain délai écoulé, elle arrête d’écouter les ultrasons.

Si elle a bien reçu les mots mêmes mots (HF et US), elle fait le calcul de distance et le stockage. Puis dans tous les cas, elle se remet en attente de réception d’un mot en haute fréquence. Si elle a 3 distances elle calcul la position. Puis dans tous les cas, elle se remet en attente de réception d’un mot en haute fréquence.

Pour transmettre un mot en ultrason, nous avons créé un protocole de communication. Le mot est transmis en modulant l’émission de l’ultrason. L’émission est considérée comme un état haut et la non-émission comme l’état bas. A cela on ajoute une base de temps. Ainsi le protocole devient une durée à l’état haut qui a une signification :

- 5 fois la base de temps représente un START
- 7 fois la base représente un 1 logique
- 3 fois représente un 0 logique
- 1 fois la base de temps représente un END
Start | 1 Logique
0 Logique | Temps mort de 1 période de temps séparant 2 bits consécutifs

Dans le mot, chaque durée significative à l’état haut (donc un START, un 1, un 0 ou un END) est séparée de 1 fois la base de temps à l’état bas. Entre les mots, on reste à l’état bas, donc sans émettre d’ultrason.

## E. Programmation

Pour des raisons de temps, les versions finales (fonctionnelles, et testées) ne sont pas très bien structurées ni commentées. C’est pourquoi nous les avons refactoré dans le dossier « Programmes Pour Le Future ». Ces programmes serviront de base pour les explications ci-dessous. Dans un premier temps, comprenez le fonctionnement, mais essayez assez rapidement de les faire fonctionner.

Les deux programmes ont une structure semblable. Le fichier ".ino" contient l’algorithme général. Toutes les variables globales sont définies dans GlobalVar.h et les méthodes sont dans Function.h. Il y a aussi les onglets de la librairie mirf. (https://itechnofrance.wordpress.com/2013/05/24/utilisation-du-module-nrf24l01-avec-larduino/) Je vous déconseille de les modifié sauf si vous est sur de vous. Pour l’onglet Function.h il y a une déclaration (Prototypage) des fonctions pour avoir un aperçu global des fonctions utilisées. Ensuite elles sont codées.
Cependant Il y a un groupe de fonctions qui sont commentées. Ces fonctions auraient due fonctionner mais nous n’avons pas réussi. À ce jour les balises fixes changent d’adresse pour parler entre elle et pour parler à la balise mobile. Normalement il est possible de définir plusieurs d’adresses d’écoute et donc cette rustine de changement d’adresse devra disparaitre. Nous n’avons pas trouvé comment utiliser cela avec la libraire que nous avions. Pour cette amélioration il faudra surement rechercher une autre libraire.

Pour que l’écriture sur le port série ne perturbe pas les balise quand nous ne le souhaitons pas, tous les Serial.print sont dans des if(debug). Les variables de debug sont dans l’onglet GlobalVar.h.

### 1. Programme pour la balise mobile

Pour travailler sur des parties isolées, si vous voulez comprendre la construction du programme final ou en cas de régression très forte, ce que je ne vous souhaite pas ! Il y a les programmes Récepteur* qui prennent pas à pas le détail des étapes à franchir. Ils sont sans doute moins bien documenté que les « Programmes Pour Le Future » mais ils ont le mérite d’isoler des fonctions.

RecepteurValidationInterruption permet de valider si les interruptions sont bien reconnues par l’Arduino à l’oscilloscope : pin 8

RecepteurMot permet de valider les mots reçus en US uniquement

RecepteurHF permet de valider les mots reçus en HF uniquement

Il y a une particularité qu’il faut qu’on vous signale car elle peut vous faire perdre un temps précieux. La variable motUS est utilisée pour le mot reçu par US et pour indexer les distances dans le tableau de distance.

### 2. Programme pour les balises fixe

Les idBalises influence le timeout pour l’attente du top. Cela a permis une synchronisation plus rapide. Tout le reste est clairement (je l’espère) défini dans le code, bonne chance. Ce programme est surement un peu plus simple à aborder pour le début.

## F. Quelques pistes d’optimisation que nous n’avons pas pu implémenter

Comme je vous l’ai déjà notifié, il y a d’autres librairies pour gérer le module nrf24l01. Dans le dossier informatique\librairie nous en avons laissé une qui devrai fonction et qui permet d’avoir plusieurs adresses écoutées.

Pour gagner en rapidité sur le calcul de position, vous pouvez calculer des positions avec uniquement 2 distances.

Pour avoir moins de rebus il y a un grand travail d’étude de la transmission ultrason. Le protocole est peut-être à repenser : les durées des états hauts ou bas, et le nombre de bits transmis.

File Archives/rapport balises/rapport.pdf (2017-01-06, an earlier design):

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

### 1 Cahier des charges – contraintes

### 2 Principe

### 3 Carte robot

### 4 Tourelle

### 5 Cartes balises

### 6 Software

### 7 Conclusion

### 8 Annexes

### 1 Cahier des charges – contraintes

Le but du système de balises de cette année est d’améliorer les balises de l’année précédente, afin de gagner en précision et en fiabilité.

a) Balises 2002
Les balises 2002 sont constituées d’émetteurs IR en tant que balises fixes émettant a tour de rôle un code modulé en 38kHz
Les récepteurs IR, au nombre de 32, et disposés en cercle permettaient de localiser la direction de chaque balise.
Les essais de triangulation ont été peu fructueux, du fait de la faible précision des mesures d’angles (pas de 360°/32)
Ce système était toutefois idéal pour localiser et aller vers un panier.
(voir rapport balises 2002 pour plus de détails)
b) Cahier des charges 2003
La principale contrainte demandée est une mesure en absolu de la position du robot (X,Y, angle), avec une précision raisonnable (exploitable plustot)
A cela s ajoutent les contraintes du règlement.
- 4 Balises compactes et autonomes (8*8*8cm) placées a 40cm de hauteur
- 1 Balise placée sur le robot adverse, compacte et autonome
- Un système (tourelle) placé sur notre robot en dessous de 40cm
- Le support de balise adverse ne doit pas gêner le repérage
- Distance mini et maximum de détection fiable : 20cm a 3m70
- Erreur de positionnement : 15cm max
- Mesure rapide (100ms max)
- Immunité aux divers parasites (électromagnetiques, IR, lumières diverses, autres lasers !!)
- Fonctionnement très fiable : jamais de position invalide en sortie
- Obiwan Kenoby

### 2 Principe

a) Généralités

Le principe adopté est un laser tournant sur le robot selon un axe vertical et émettant horizontalement.
Chaque balise captant le passage du laser peut donc déduire un angle grâce a la mesure du temps de passage.
Les balises fixes peuvent donc calculer la position du robot, et renvoyer celle ci, mais au fur et a mesure de l’avancement du projet nous avons préféré renvoyer un code pour chaque balise, et donc faire les calculs de triangulation uniquement dans le robot.
Quand une balise est touchée, elle émet une trame qui l’identifie, grâce a des diodes IR.
Le robot reçoit cette trame et en déduit l’angle ou se trouve cette balise, pour ensuite effectuer la triangulation.
Pour la balise adverse, le principe est le même a part que la fréquence est différente, et on inclut une information de distance.
Pour mesurer cette distance, on utilise 2 lasers parallèles et on mesure le temps de passage de chacun sur la rangée de photodiodes de la balise.

Vue de coté

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


b) Tourelle

La vitesse de rotation de la tourelle est d’environ 20tr/sec (vitesse asservie).
Elle est construite sur une base de tête de lecture de magnétoscope, dont on utilise le moteur brushless et les transformateurs entre le rotor et le stator.
On y a monté 3 lasers parallèles si on regarde de dessus, et ayant des inclinaisons différentes si on regarde de coté.
On trouve également une carte réalisant l’alim de ces lasers et comportant les 2 récepteurs IR (30 et 56kHz). Cela permet d’avoir toujours les récepteurs pointés vers la balise dont on reçoit la trame.
Les liaisons entre cette carte et le robots passent a travers 3 transformateurs dont le primaire et le secondaire sont situés sur le rotor et le stator.
c) Liaison laser

Les lasers ne sont pas modulés, mais comme ils passent assez rapidement sur les photodiodes on fait un filtrage passe haut sur chaque diode.
En outre, on utilise des filtres numériques basés sur le nombre de détections simultanées : chaque balise ayant une rangée de 18 photodiodes, un laser ne peut en déclencher 3 côte à côte au maximum, on utilise donc ce phénomène pour filtrer les parasites agissant sur plusieurs photodiodes disjointes, ce qui est très éfficace.
De plus le laser n étant pas diffusé, la lumière reçue par une photodiode est assez conséquente, donc le seuil de détection peut être reglé assez haut, ce qui eliminé encore des parasites.
d) Liaison IR

La liaison de retour utilise des diodes IR (8 par balise) pour retransmettre les trames de chaque balise au robot.
Quand une trame est émise, les 4 cartes balises émettent simultanément, cela permet d’atténuer les différences de réception entre balises (le CAG des récepteurs IR faisait que l’on ne voyait pas la balise la plus éloignée)
La modulation des balises fixes est a 56kHz, la balise adverse fonctionne a 30kHz. Cela permet des trames plus courtes pour les balises fixes, dont l’enchaînement peut être assez rapide.
D’ailleurs si le laser touche la balise suivante alors que la trame n est pas finie, cette balise sera ignorée.

Une trame de balise fixe se compose de 4 bits : Start, MSB, LSB, stop
Le bit de Start est a 1, le stop a 0, et les 2 bits utiles codent le numéro de balise fixe. Chaque bit dure 10 périodes de modulation (179us)

Pour la balise adv, la trame contient un seul état haut qui dure d’autant plus longtemps que la balise est proche.

e) Le traitement

Le traitement, outre les filtres, est un calcul trigonométrique effectué sur 3 angles (3 balises, la 4eme est ignorée si on en reçoit 4).
On en déduit la position X, Y, thêta du robot sur le terrain.

### 3 Carte balise contenue dans le rack du robot

IR 56kHz; LASER; IR 30kHz; Buffer; Alim; Transfo; Mise en forme; pont en H; Top Tour; Moteur; Hacheur; MICROCONTROLEUR; Reglage; Oscillateur; Dialogue CM; Alim Puissance; Carte Balise Robot; Tourelle

Sur cette carte qui dessert la tourelle, on trouve un ATMEGA163, un oscillateur et un pont de puissance destinés a alimenter l’électronique de la tourelle, une alim pour le moteur brushless de tourelle, et enfin des étages de traitement des capteurs : top tour et les 2 capteurs IR 30 et 56kHz.

a) Alim tourelle

La tourelle étant alimentée au travers d’un TRANSFORMATEUR, il faut une alim alternative.
Elle est constituée d’un oscillateur (U2) dont on peut ajuster la fréquence entre 500kHz et 1MHz. Une fréquence plus basse peut brouiller les récepteurs IR ou bien faire saturer le transfo.
Cet oscillateur sort 2 signaux carrés en opposition de phase. Ces 2 sorties peuvent être forcées par un signal venant du contrôleur. On peut donc éteindre l’alim de la tourelle afin de couper le laser quand il n est pas nécessaire, ou pour des raisons de sécurité, si le uC remarque que la tourelle ne tourne pas. En mode programmation, les sorties étant en haute impédance, R15 permet d’éteindre la tourelle.
Les 2 sorties de l’oscillateur pilotent des interfaces de puissance rapides, U4 et U5 qui sont en fait des drivers de MOSFET. Ce choix n’est pas très judicieux, car ils sont un peu limites au niveau puissance et temps de commutation, mais cela à fonctionné. Par contre, contrairement au schéma, il ne faut surtout pas utiliser 2 amplis en parallèle, car, leur seuil n’étant pas exactement le même, l’un peut commuter avant l’autre, et on se retrouve en situation de court circuit! Sur la dernière carte utilisée ces pistes on donc été coupées. Il faut absolument trouver des composants de remplacement pour l’année prochaine.
En sortie, on trouve un réseau RC limitant le courant et supprimant une éventuelle composante continue.
b) Alim moteur

Le moteur étant du type triphasé synchrone, et possédant sa propre électronique de commutation, on l’alimente normalement avec une tension continue.
U12 est un régulateur de tension réglable servant à ajuster la vitesse
Ce régulateur peut être désactivé par le uC via T1 & T2 qui forcent la patte ADJ du régulateur a 0V, d’ou 1,25V en sortie, ce qui empêche le moteur de tourner. Ce montage a 2 transistors sert a ce que la tourelle s arrête en cas d’absence d’alim logique, et R16 devait bloquer le fonctionnement pendant la programmation du contrôleur, mais a été mise a VCC au lieu de la masse (ah ces sabotageurs….)
Apres quelques essais, il s est avéré que la vitesse de la tourelle pouvait fluctuer, et nous avons donc décidé de l’asservir, ce qui a été fait a l’aide du top tour, mais alors comment commander le moteur de façon analogique ? Eh ben on a appliqué une PWM (de l’ordre du kilohertz) sur la commande moteur, c est vraiment pas propre du tout comme solution, car l’électronique du moteur est alimentée par intermittence, mais ça marche !
En plus olivier a programmé un super asservissement, la vitesse est très stable.
On peut envisager l’an prochain de commander directement les 3 phases du moteur par des sinus PWM, a voir….
c) Traitement des capteurs IR

Les informations des 2 capteurs IR passant par les fameux transformateurs, arrivent sous forme de la dérivée du signal. Il est donc nécessaire de remettre en forme ce signal pour pouvoir l’exploiter correctement avec le uC. Astuce de sioux, on utilise un NE555 (un par voie, U10 et U11). Ce circuit est câblé ici en comparateur a hystérésis (1/3 et 2/3 de VCC), ou plustot comme comparateur a fenêtre suivi d’une bascule RS, mais ça revient au même, voir DS du NE555.
Une des bornes du transfo est reliée a une référence de tension (ajustable, car il y a des dissymétries), l’autre borne du transfo est reliée a une résistance de charge (variable pour ajuster l’amplitude) et aussi a l’entrée du 555.
Quand le signal d’origine du capteur passe de 0 a 1, une impulsion positive très courte est reçue et met la sortie du 555 a 0, et elle y reste car la tension repasse a VCC/2.
Pareil pour le passage de 1 a 0
Voilà a quoi ressemble le signal sortant d’un transformateur : dessin
A améliorer ici : le circuit du transformateur oscille, et les réglages sont délicats car après le pic principal, il y en a un plus faible, négatif.
d) Capteur top tour

Le capteur de tops tours subit le même type de traitement que les capteurs IR car il donne le même type d’information.
On a juste un amplificateur en plus car le niveau est trop juste pour atteindre les 1/3 – 2/3 de VCC
e) Divers

Bon, à part le contrôleur il reste pas grand chose à dire sur la carte, le découplage est vital ici, vu que des signaux HF côtoient des infos plus faibles venant des transformateurs.

### 4 Tourelle

a) Mécanique

La mécanique de la tourelle est un scanner de magnétoscope VHS 4 têtes ( tête de scope + moteur + transfos – têtes de lecture + lasers + carte alimentée + lasers = tourelle de balise laser , c’est l’équation magique)
On a enlevé les têtes du tambour, puis M. DELAUNAY y a fraisé 3 rainures pour le logement des lasers avec des vis de maintien et un capot par dessus.
Un contrepoids de plomb, coulé dans le tambour assure l’équilibrage de tout le système.
Les lasers ont des inclinaisons (ajustées a coups de lime sur le corps des diodes laser) différentes pour qu’il y ait au moins un laser qui atteigne la cible quelle que soit la distance (20cm-4m)
Le tambour est en fait monté a l’en vers pour laisser de la place a la carte électronique, qui est tournée a son emplacement pour être équilibrée, et ne pas avoir de saillie sur le système (25 tr/sec c’est pas rien).
Le moteur est laissé tel quel, il a juste fallu identifier les connections.
La tourelle entière est placée sur un support ajustable fixe au rack elec.
Autour de la tourelle, un morceau de bouteille plastique sert à supporter le support de balise.

C'est une très bonne mécanique, idéale pour cette application, et M. DELAUNAY a fait du très bon travail, comme d’habitude.

b) Électronique

On y trouve d’abord l’alim : un pont redresseur de 4 diodes rapides avec un filtrage. Les lasers sont juste alimentés a travers une résistance de limitation chacun (méthode douteuse, ils se dégradent avec le temps…) et une résistance pour ajuster l’intensité globale. Un régulateur fournit l’alim pour les récepteurs IR.

4 récepteurs IR étaient prévus, un couple 30 et 56 kHz dirigé dans le même sens que les lasers, et un vers l’arrière, avec un interrupteur pouvant sélectionner entre les fréquences, mais finalement on a utilise que les capteurs avant.
Les capteurs commandent des buffers qui envoient les impulsions sur les 2 transfos, et sur des leds de visu (c est joli la nuit…)

Cette carte est assez touffue, l’espace est limité, et surtout elle doit être a peu près
équilibrée mécaniquement!!
(le 1

er
qui me trouve un autorouteur qui fait ça gagne un AVR)

### 5 Balises

Filtre logique; Carte Balise (4 exemplaires sur le bus); PHT; Filtre + Seuil; Filtre; temporel; visu; Generateur de trames; Diodes IR; Puissance; Modulation; Horloges; E MIS; SIO; Alims; BUS INTER-BALISES; Xilinx XC9536 XL; filtre; Vref; Alim; oscillateur; Fusible-Inter; Batterie; 560kHz; 5,6kHz; 56kHz

Les 2 systèmes de balises (fixes et adverse) sont composées d’un pack d’accus de petites dimensions (7* AAA), d’une carte d’alim, et de 4 cartes balises dialoguant sur un bus et comportant chacune émetteurs, récepteurs, et traitement.

a) Carte d’alimentation – horloge

Le pack batteries étant de 8,4V étant de y trouve un régulateur a découpage sortant la tension pour la logique (3,3V), mais aussi, grâce a un 2

ème
enroulement sur la self, la tension de polarisation des photodiodes (~30V, max 20mA). Ici cette tension dérivée est obtenue par un fonctionnement de type boost, afin de maintenir la tension constante, il vaudrait mieux inverser le 2

ème
enroulement et lui bobiner plus de spires (10*44, dur dur….). Attention à ne pas dépasser les 40V (tension max photodiodes)
On trouve aussi sur cette carte un oscillateur (U2) servant a clocker les xilinx des cartes balises. La fréquence retenue est de 560kHz fréquence qui permet, par division d’obtenir les 56kHz d’émission IR, mais cette horloge sert aussi a échantillonner les signaux d’entrée, et comme le temps de passage du laser peut être très court, il faut s’assurer qu il sera toujours assez supérieur a cet échantillonnage, d’ou cette valeur élevée.
On trouve encore sur cette carte inter marche arrêt, fusible, 2 résistances de tirage pour le bus inter cartes (R4-R5) et enfin un potentiomètre ajustant la référence de tension de comparaison.
b) Carte balise

On a tout d’abord 18 récepteurs complets, comprenant une photodiode, suivie d’un filtre passe haut, puis d’un comparateur.
La photodiode est polarisée par une résistance a une tension élevée (Vpol = 30V) afin de ne pas saturer pour des lumières continues tout en gardant une sensibilité assez élevée (déterminée par R1)
Le filtre passe haut C1-R19 est dimensionné afin de laisser passer les impulsions laser, que la distance soit faible ou élevée, avec une vitesse de rotation mini de 10tr/sec.
Le 50/100Hz ambiant est bien filtré(voir chronogrammes relevés).
Le comparateur indique quand un pic dépasse Vref.

Les 18 récepteurs constituent donc une barrette de détection qui signale quand le laser passe sur la balise et à quel niveau.
Les photodiodes on été implantées légèrement en biais pour éviter les zones mortes entre elles.

Passons à l’autre schéma :
Derièrre chaque comparateur on trouve une résistance de pull up.
Les comparateurs a collecteurs ouverts ont été choisis pour plusieurs raisons : les xilinx sont alimentes en 3v3, et les comparateurs en 8,4V, et en plus ça évite un parasitage trop important de l’alim des AOP pendant la commutation.
D’ailleurs toutes les tensions arrivant a la partie analogique sont filtrées sinon on aurait du bruit venant des couplages (4m de câbles, commutations IR, logique, alim a découpage…) Vref est aussi divisée pour éviter de transporter une tension trop faible sur plusieurs mètres.

Le xilinx XC9536 XL (3v3) a été choisi car c’est le moins cher ! (~4E) On y entre les 18 entrées, les 2 lignes de bus inter cartes (+ une autre pour l’horloge commune).
On avait prévu un oscillateur a quartz, mais il ne fonctionne pas directement sur le xil, on s’est en fait servi de son implantation pour mettre un filtre qui épure l’horloge reçue (100p/10K ?), car après qqes mètres d’une liaison non adaptée, l’horloge est assez crade (adapter la liaison ??)

Le xilinx est également relié au connecteur de programmation, prolongé par un connecteur de test sortant 4 signaux pour le debug (très pratique !!).
On trouve aussi 3 leds de signalisation et la commande de puissance des leds IR qui se fait en 2 puissances par des transistors mos.
Ce schéma est a améliorer : pdt la programmation les mos flottent => res de tirage obligatoire, et il serait bon de limiter le courant constant pouvant accidentellement circuler dans les leds (condensateur ??) Le réglage du courant était utile, pas les 2 niveaux…

Par contre le xilinx était un peu étroit pour toutes les fonctions nécessaires, un 9572 aurait été confortable, mais on ne le trouve pas en 44pins.

c) Software VHDL

Il contient pleins de modules :
-horloges : diviseurs générant une horloge d’échantillonnage(560kHz), une horloge modulation(56) et une horloge bit de trame (5,6kHz)
-capteurs : équations logiques qui permettent d’éliminer les cas interdits (2 récepteurs distants activés par ex.)
-timers : compteurs qui permettent la validation d’une détection. Par ex si une détection invalide suit une valide (ou inversement), l’ensemble est invalide. Sans ce filtre, le précédant ne sert a rien, car lors d’une erreur les 2 récepteurs ne s’activent pas forcément en même temps !
Pour pouvoir dévalider par après une détection valide, on retarde en fait la sortie et on annule si entre temps il y a une erreur.
-gener_trame : module générant la trame (personne ne s’en doutait…) en fonction du numéro de balise, et des qu’il y a détection valide.
-carte : module avec les déclarations générales, et qqes fonctions qui devraient être un peu mieux rangées
-testbench : banc de test de simulation, qui produit quelques signaux de test

La liaison avec les autres cartes est faite sur 2 lignes en collecteurs ouverts(à VCC) occupé est mis a un par la balise qui émet sa trame pour empêcher les autres de commencer aussi une trame, et emission_ext fait émettre les autres balises en même temps, pour les problèmes de CAG récepteurs IR. Ces lignes étant des collecteurs ouverts sont donc bidirectionnelles, entrées en temps normal et sorties quand on génere une trame.

Tout ce code est vraiment très optimisé (crade quoi), car le xilinx est vraiment juste. Ce n’est pas écrit de façon synchrone, on a parfois des complications a cause de ça, surtout si l’alim n’est pas propre (pics de commutation des IR par ex…)

Pour le module balises adv, quelques changements sont a noter : à la première détection, un compteur démarre a partir de 0, à la 2 eme il change de sens et son horloge ralentit, et on émet des IR tant qu il n est pas a 0, donc on émet une durée proportionnelle a la durée entre les 2 lasers (mesure de distance approx)

### 6 Software

a) Non ce n'est pas le bordel

Ce code est fait très proprement. A quelques détails près. Ca a été fait un peu dans l'urgence, comme chaque année, et comme toutes les équipes.

Voici la liste des modules importants :
- main : Ben les inits de départ et la boucle principale.
- tourelle : gestion de la rotation de la tourelle et de l'allumage des lasers.
- traite : décodage des signaux IR, calcul de la position
- rtc, SPIpfd*, ap_uart, printf_P, utils, attente : les grands classiques des programmes du robot. On retrouve ces modules partout, reportez-vous au rapport sur le soft général (comment ça y'en a pas ?). Bon j'en parlerai vaguement plus loin.

Il n'y a pas tant de choses que ça, on va essayer de boucler ça vite fait bien fait.

b) L'algorithme

Cahier des charges

Tof aime bien mettre des cahier des charges alors je lui en met un ça lui fera surement vachement plaisir.

- Décoder les signaux

Ceci peut être fait soit en mémorisant les signaux et en faisant un décodage après en une seconde passe, soit en décodant à la volée les signaux reçus.

- Avoir une mesure de l'angle la plus précise possible pour chaque balise

La mesure d'angle va se rapporter à une mesure de temps, nous l'avons vu, car la tourelle retourne un TOP à chaque tour. Ce point implique deux choses : Le décodage doit être rapide (peu d'instructions) afin de ne pas ralentir la mesure du temps sur les timers, ou tout du moins ce temps de traitement doit être connu et constant. En second lieu, la vitesse de la tourelle doit être constante et connue (asservie en fait). Bon là je fais comme si c'était évident qu'il fallait l'asservir mais en pratique ça a mis quelques semaines avant qu'on ne se décide.

- Retourner une position juste sinon ne rien retourner

C'est pas trivial. Il s'agit de recenser un maximum de cas que l'on considérera comme des cas d'erreurs. On essayera de discuter de ça un peu plus bas.

Une première idée

On a vu (tof l'a expliqué non ?) que les sorties des capteurs IR sont reliés aux broches d'interruptions externes INT0 et INT1 du microcontrôleur. Il est possible de configurer ce dernier pour qu'une routine d'interruption s'exécute sur n'importe quel front (je rappelle pour ceux qui ne suivent pas qu'il existe deux fronts, le montant et le descendant... je ne vous ferais pas l'affront de croire que vous ne le saviez pas). L'idée géniale est d'avoir un timer qui tourne en permanence et à chaque changement d'état sur une broche d'interruption (INT0 = balises fixes et INT1 = balise adverse) la valeur de ce timer est sauvegardée dans un tableau. Lorsque le tableau est plein (la taille doit être adaptée), on le parcourt et on décode les trammes.

Lorsque l'on a récupéré les angles de chaque balise, on a facilement la position du robot. En fait, trois balises suffisent. Nous verrons dans au paragraphe suivant l'équation qui permet d'obtenir la position à partir des angles des balises relatifs au robot.

Revenons à notre idée. Pourquoi il y a mieux ? Déjà car c'est un peu lent, on est obligé d'attendre que le tableau soit plein (en plus il faut qu'il soit suffisamment grand pour contenir a coup sûr les trammes des 4 balises). Et une fois qu'il est plein, il faut décoder, puis faire le calcul. C'est un fonctionnement un peu trop séquentiel à mon goût. Y'a aussi une autre raison : j'ai commencé à réflechir au code, et je me suis rendu compte que j'étais mal parti. Bref, je suis reviendu au point de départ.

Une deuxième idée

Cette deuxième idée met en place un décodage des trammes à la volée dans la fonction d'interruption. Pour chaque broche d'interruption, on a un séquenceur : il est d'abord en mode attente, puis en fonction du front qu'il reçoit et du moment auquel il arrive, le séquenceur détermine si une balise a été captée, si on doit attendre la suite du signal ou si le signal n'est pas conforme (dans ce cas il y a une erreur et on attend un "trou" pour se resynchroniser).

Voici un petit schéma qui représente bien le fonctionnement de l'automate. A chaque front, l'automate décide dans quel état passer. Les temps qui figurent sur le schéma ressemblent aux temps utilisés dans la version finale (300 us par bit), mais ils ne sont là qu'à titre indicatif. Il est intéressant de comparer l'automate avec les trammes séries que l'on reçoit : "1000" pour la balise 0, "1010" pour la balise 1, "1100" pour la balise 2 et "1110" pour la balise 3.

Pour la balise adverse, c'est pareil mais en plus simple.


Il reste encore a mémoriser le temps à chaque start pour connaître le moment précis du début de l'émission, ce qui n'est pas trop difficile. Une fois qu'on a les temps pour chaque balise, ils sont convertis en angles relatifs au robot, on filtre un peu (du genre "tiens la balise 2 était à 94 degrés il y a 100 ms et maintenant elle est à 200 degrés" => invalidons la mesure). Puis on calcule la position (x,y,a), on refiltre un peu (histoire que la position du robot ne bouge pas de 25 mètres entre deux mesures, d'ailleurs il n'est plus sur le terrain), et le tour est joué.

Des détails dans la partie Implémentation.

Je vous remet encore une petite idée ?

Allez c'est la fête c'est ma tournée d'idées. Il y a un défaut majeur dans le code des balises, mis à part le fait que c'est pas super propre.

Le problème est que l'horloge de l'automate est synchrone aux transitions. Ce n'est pas très grâve à première vue mais c'est vite gênant : Pour détecter un "trou" (absence de signal IR) il faut attendre le front montant suivant. Pas cool.

D'ailleurs cet automate pourrait être bien mieux défini. Déjà je pense que l'automate doit être dans une boucle a part (dans RTC par exemple). Et il faut pouvoir ajouter en plus des deux tokens "front descendant" et "front montant" (Yves ?) un token "aucun front". On sait alors qu'aucun front pendant plus de 1ms signifie un "trou". Bon ça a pas l'air révolutionnaire comme ça, mais croyez-moi, ça évitera plein de saloperies dans le code.

c) Le code

J'ai préférer appeler cette section "le code" plutôt que "l'implémentation", car au moins on sait qu'un code c'est censé être difficile à déchiffrer.

Deux petites généralités avant de commencer :

- Il y a beaucoup de variables globales, pour la simple et bonne raison que des variables locales ça va dans la pile ou dans les registres, et sont créées à chaque appel de la fonction. C'est donc plus lent car le compilo doit sauvegarder le contexte, et on veut que l'interruption soit traitée le plus vite possible : rappelez-vous, la mesure du temps doit être précise. Enfin, je dis ça, c'est quand même un peu con d'avoir un code qui fait la mesure du temps à la microseconde près alors que le capteur infrarouge a une incertitude bien plus grande.
- le mot clé "volatile" signifie pour une variable que sa valeur est toujours à jour dans son emplacement mémoire. En effet, par exemple, il arrive que lors d'un calcul utilisant et modifiant une variable globale normale, le compilo souhaite optimiser et stocke les résultats intermédiaires de cette variable dans un registre. Parfois, dans une boucle, certaines variables ne sont utilisées qu'en tant que registre. Il y a de fortes chances que le programme suivant ne fonctionne pas :

int a;

SIGNAL(SIG_INTERRUPT0) {
lcd_printf("%d\n",a);
}

int main() {
while(1)
debug_printf("%d\n",a);
}

La variable a doit être déclarée par :

volatile int a;

Les modules standards

- utils : c'est un module qui permet un accès plus évolué à la mémoire EEPROM. On y place aussi les macros ou fonctions inline de bas niveau. Ne sert à rien sur cette carte (mais que fait-il là alors ?).
- ap_uart : transmission et réception de caractères sur la liaison série. La liaison série pouvait être aiguillée vers le PC grâce au Xilinx, pour débugger.
- rtc : une interruption qui a lieu toutes les 256 us. Tiens encore un module qui n'a servi a rien.

- SPIpfdS : SPI, protocole full-duplex, coté esclave. Des fonctions de bas niveau pour l'émission et la réception de données vers la carte mère (le maaaaîître).
- SPIpfd : Les différentes commandes et statuts qui constituent les dialogues avec la carte mère.
- attente : Ben des fonctions de tempo, tout ce qu'il y a de plus bête. Ce sont des boucles dont la longueur est calculée pour mesurer un temps précis. Attention tout de même le processeur est monopolisé pendant tout ce temps.
- printf_P : Implémentation du printf. Il y a uart_printf qui envoie les données vers l'uart (fonction bloquante, lente, mais simple). Et il y a aussi debug_printf qui n'est pas bloquant (car tout est écrit dans un buffer et émis sous interruptions). Si debug_printf est appelé alors que le buffer précédent n'est pas vide, il est ignoré.
- debug : contient des fonctions appelées par le debug_printf. Il y a 3 fonctions, une pour emettre un caractère (il est en fait copié dans un buffer), une pour emettre le buffer (appelée à la fin du debug_printf) et une pour savoir si un buffer est en cours d'émission ou non.

Le module tourelle

Ce module sert à asservir la vitesse de la tourelle. L'asservissement est plutôt mou et lent, mais il est assez stable. On n'a de toute façon pas besoin d'un temps de monté rapide. Lorsque l'on allume le robot, même avec la commande à fond, le moteur met un certain temps à atteindre sa vitesse de croisière.

Les lignes suivantes servent à générer un PWM lent sur le timer 2. En modifiant la valeur du registre OCR2 (Output Compare Register), on change la valeur du PWM.

INTERRUPT(SIG_OUTPUT_COMPARE2)
{
MOTEUROFF();
}

INTERRUPT(SIG_OVERFLOW2)
{
MOTEURON();
}

On se sert du timer 1 pour :
- mesurer la vitesse de la tourelle
- declencher l'asservissement de cette dernière toutes les 65 ms
- mesurer les temps des détection des balises (on va le voir plus bas)

Ce timer 16 bits tourne en boucle à 1Mhz (incrémentation toutes les microsecondes).

Voici comment fonctionne la mesure de vitesse de la tourelle :
Le Input Capture Port est relié au top tour de la tourelle. A chaque top tour, la fonction SIGNAL(SIG_INPUT_CAPTURE1) est appelée. Elle sauvegarde la valeur du timer 1 à ce moment ansi que la valeur du timer 1 lors du précédent top tour. Il suffit de faire la différence de ces deux valeurs et on a le temps que met la tourelle pour faire un tour (il est de l'ordre de 25 ms à fond). Enfin, il faut s'assurer que la tourelle ne tourne pas moins vite que 65ms, sinon notre différence de valeur de timer sur 16 bits ne veut plus rien dire. C'est le rôle de la variable temps65536us qui est incrémentée à chaque top tour et remise à zero à chaque overflow. Si lors de l'appel de l'asservissement cette variable vaut 0, alors la tourelle tourne trop lentement, donc on met la gomme.

Si le moteur est trop lent pendant plusieurs appels de l'asservissement, on en profite pour éteindre le laser pour des raisons de sécurité.

Sinon l'asservissement est une sorte de proportionnel-intégral un peu batard. Je vais pas détailler trop ça, il faut juste savoir que ça marche (promis l'année prochaine je le fais mieux).

Le module traite

De quoi traite ce module ? hum... Il fait le gros du boulot, décodage et calcul.

En fait rien de dur. C'est long mais pas difficle. Il s'agit de la "traduction" de l'automate vu dans la partie précédente. Sauf qu'il positionne les variables utlisées dans le main. C'est là que c'est pas propre (oui le reste passait encore). Entre le tempsMachinActuel ou tempsTrucRec2PrecedentStocke, j'avoue qu'on s'y perd un peu... euh... ok beaucoup.

Déjà le principe est compris je pense, il s'agit de retourner le temps qui correspond à la balise détectée. Mais comme on l'a vu dans le partie Algorithme, il n'est pas possible de détecter un "trou" tant que le front montant suivant n'est pas survenu. En clair, impossible de valider la détection de la balise n tant qu'on a pas chopé le front montant du bit de start de la balise n+1.

On se retrouve à fournir la valeur de certaines balises en retard, et il est alors impossible de déduire l'angle de la balise car on ne sait pas par rapport à quelles valeurs du topTour elle est définie. Bref, on doit fournir des infos supplémentaires au main (la valeur du topTour qui correspond à la dernière balise détectée, ...et d'autre trucs dont plusieurs ne doivent plus servir à rien). Résultat : cette partie est imbittable, démerdez vous. ;)

Ce qui aurait pu être bien, c'est la réinitialisation du timer à chaque top tour (on executerait l'asservissement de la tourelle par la rtc du timer 0), de façon à ce que la référence ne bouge pas à chaque tour. Le problème c'est que la mesure des temps entre deux fronts ne pourrait plus se faire par une simple soustraction de la valeur actuelle du timer par la valeur précédente (en modulo 16 bits, comme le timer).

Dans ce module il y a également une fonction qui calcule la position du robot en fonction de l'angle des balises. Ça marche très bien. C'est une équation générée par crazyfred et lebomb avec Maple. Elle a été optimisée à fond et j'ai été épaté par le peu de temps que mettait le uC pour faire ce calcul (je sais plus exactement ais j'aurais dit 1 ou 2 ms).

Le module main

Voici son fonctionnement global :

initialisations
faire à l'infini
| si une balise a été récupérée
| | calculer son angle
| si on a 3 mesures récentes, fiables, et tout et tout
| | lancer le calcul de la position

C'est tout con, mais il n'empêche que c'est pas évident à trouver quand on a que le code sous les yeux. Tout comme le module traite, c'est vrai que c'est pas du grand art en propreté de code. Heureusement j'ai toujours l'excuse "on était pressé", et d'ailleurs c'est loin d'être faux.

Conclusion

Donc, à améliorer, la détection des "trous" en plaçant le séquenceur sous rtc aussi. Eventuellement trouver un uC qui a un timer 16 bits en plus ou utiliser un 8 bits + un compteur. Proprifier le tout, Ajouter un peu de sel et c'est parfait.

Le principe est là, il faut maintenant peaufiner l'implémentation
(c'est marrant je crois que j'ai dû conclure sur un truc un peu pareil pour la carte son).

### 7 Conclusion

a) Qu il est bien ce système ! (louanges …)

Ce système a donne satisfaction par sa fiabilité ( même si on l’a pas utilisé en match ). Ses points forts sont :
- Précision suffisante
- Fiabilité très bonne (on a pas vérifié lors du match de 16eme,mais je pense qu elles fonctionnaient)
- Facilite d’utilisation, pas de réglages compliqués, a part à la fabrication (lasers)
- Position presque instantanée, a 25 Hz.

En gros c’est un très bon système, fiable même si il est complexe.
Je pense qu’en 2003, aucune autre équipe n’avait un repérage absolu aussi efficace ! L’an prochain il va sûrement être très utile car il y aura des objectifs fixes a atteindre avec assez de précision (apparemment le règlement choisi est un rugby).
b) Qu’il est pas bien ce système ! (Améliorations – Défauts)

On peut encore améliorer ce système l’an prochain, car il y a encore quelques défauts
- Précision de 10cm pas encore satisfaisante, probablement la faute à la prise en compte des angles dans les calculs
- La transmission IR est lente, on pourrait la remplacer par de la HF. Avec de la HF, la tourelle est simplifiée (récepteurs fixes), et on peut transmettre beaucoup plus d’infos. Le traitement peut ensuite être fait dans les balises, en ajoutant un uC (un seul pour 4 balises), qui s’occuperait du calcul, codage et transmission.Ca permet de décharger les xilinx et aussi d’avoir la position pour debug depuis une partie fixe (bal fixes). On peut aussi estimer les distances et revérifier la cohérence générale.
- les lasers devraient être asservis en luminosité, et pas seulement ajustés en courant
- le moteur peut être commandé directement en triphasé, certaines têtes ont peut être aussi un moteur CC
- le filtrage de la mise en forme des transfos est à améliorer
- le pont en H d’alim tourelle chauffe trop
- Les filtres temporels ne sont pas encore prévus pour un autre système de laser balayant (adverse) : Le principe est d’ignorer tous les signaux qui ne sont pas cycliques exactement à la fréquence de rotation (s’arranger pour avoir 2 freqs commutables)
- La liaison IR peut servir à faire une balise du même type que l’an dernier en cas d’urgence (panne par ex, ou manque de temps), mais ça prend aussi du temps
- Pb de liaison IR : la balise 3 est assez mal reçue, probablement car son impulsion est longue (récepteur pas prévu pour ça !)
- Bon on a des balises qui fonctionnent, il faudrait penser à les utiliser !!
c) Remerciements

Merci à l’ENSEIRB qui nous donne les moyens de réaliser nos projets.

Un grand merci au personnel de l’ENSEIRB qui nous soutient :

M. DELAUNAY pour son travail toujours de très bonne qualité, M. LEGALL, notre bien aimé magasinier, M. MICOULEAU, M. LALANDE, et nos profs de parfois tolérer nos petites absences.

Nos sponsors, qui sont également des partenaires très precieux, sont : GERTRUDE, ALTARES, l’UNIVERSITE DE BORDEAUX I, MICRO SYSTEMS, et le
CREDIT MUTUEL

Merci à M. LAUNAY, et M. HOCHENOFFER, de l’ENSAM, pour leur contribution à la mécanique.

Les membres du club awant travaillé sur les balises sont :

Olivier MATZ pour la partie code
Olivier CAMBON & Christophe RIEHL pour l’électronique Olivier CAMBON et Frédéric LOCHON pour la partie calculs

### 8 Annexes

Les schémas sont dans des fichers séparés, ps ou pdf
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

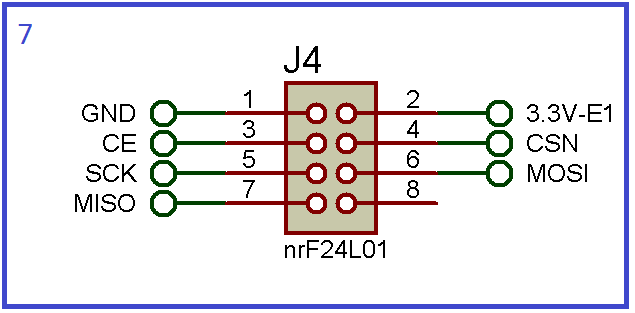
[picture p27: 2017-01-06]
Rapport/Fichiers supports/ImagesElec/E7 HF.bmp

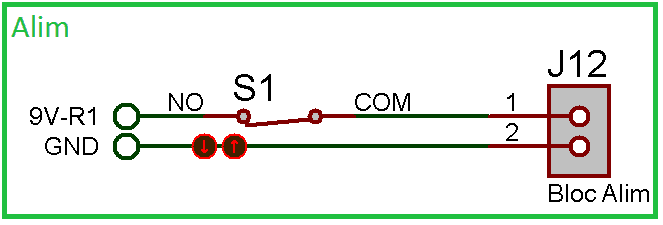
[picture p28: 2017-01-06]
Rapport/Fichiers supports/ImagesElec/RAlim.bmp

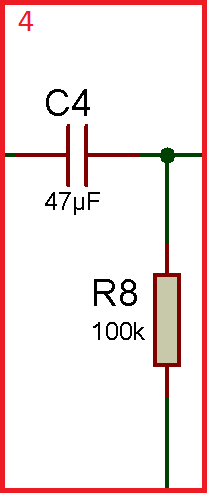
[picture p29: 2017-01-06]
Rapport/Fichiers supports/ImagesElec/R4 filtre continu.bmp

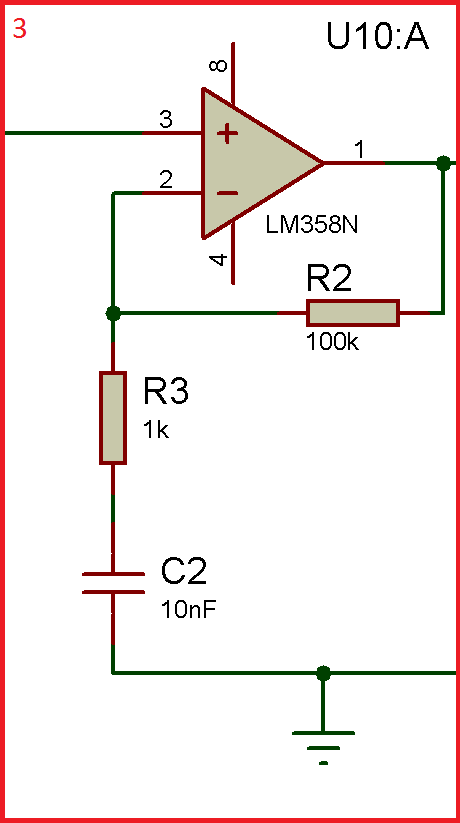
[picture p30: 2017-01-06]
Rapport/Fichiers supports/ImagesElec/R3 x100 sauf le constant.bmp

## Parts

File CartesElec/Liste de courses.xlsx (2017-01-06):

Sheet: BOM
Bill Of Materials for
Design Title
Author |  | Bruno Bellier
Document Number
Revision |  | 1
Design Created |  | jeudi 17 septembre 2015
Design Last Modified |  | vendredi 9 octobre 2015
Total Parts In Design |  | 32
 |  |  |  |  |  |  | Totals
Category | Quantity |  | References | Value | PrixUnitaire | Prix | Category | Quantity
Support | 2 |  | dil aop | 8 |  | 0.00 | Condensateurs | 16
Support | 3 |  | dil non | 16 |  | 0.00 | Resistors | 16
Support | 3 |  | dil nand | 14 |  | 0.00 | Integrated Circuits | 0
Support | 4 | 5 | header | 30 | 0.54 | 2.68 | Diodes | 0
Support | 4 |  | header hf | 8 |  | 0.00 | Miscellaneous | 0
Switch | 9 |  | monostable |  | 0.11 | 0.00 | Total | 32
LED RGB | 3 |  |  |  |  | 0.00
arduino nano | 4 | 5 |  |  |  | 0.00
 |  |  |  |  |  | 0.00
 |  |  |  |  |  | 0.00
 |  |  |  |  |  | 0.00
 |  |  |  |  |  | 0.00
 |  |  |  |  |  | 0.00
 |  |  |  |  |  | 0.00
 |  |  |  |  |  | 0.00
 |  |  |  |  |  | 0.00
 |  |  |  |  |  | 0.00
 |  |  |  |  |  | 0.00
 |  |  |  |  |  | 0.00
 |  |  |  |  |  | 0.00
 |  |  |  |  | Total | 2.68

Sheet: Etat des courses
Liste Matériel avec coût
Category | Quantity | Acheter | Trouvé | A acheter | References | Value | PrixUnitaire | Prix
Condensateurs | 3 | 3 | 0 | 0 | C0 | 560pF | 0.30 | 0.90
Condensateurs | 4 | 0 | 4 | 0 | C1,C18 | 330nF |  | 0.00
Condensateurs | 7 | 0 | 7 | 0 | C2-C3,C19 | 100nF |  | 0.00
Condensateurs | 12 | 8 | 4 | 0 | C10-C11,C14-C15 | 10nF | 0.30 | 2.40
Condensateurs | 12 | 5 | 7 | 0 | C12-C13,C16-C17 | 1nF | 0.30 | 1.50
Resistors | 27 | 24 | 3 | 0 | R0,R10,R12-R14,R18,R20-R22 | 100k | 0.10 | 2.40
Resistors | 6 | 5 | 1 | 0 | R11,R19 | 1k | 0.10 | 0.50
Resistors | 6 | 0 | 6 | 0 | R15,R23 | 3.9k |  | 0.00
Resistors | 6 | 0 | 6 | 0 | R16,R24 | 10k |  | 0.00
Resistors | 6 | 0 | 6 | 0 | R17,R25 | 1M |  | 0.00
NON | 3 | 3 | 0 | 0 | U0 | 4049 | 0.95 | 2.85
NAND | 5 | 0 | 5 | 0 | U1,U13-U14 | 7410 |  | 0.00
Bornier à vis | 4 | 0 | 4 | 0 | U2,U11 | TBLOCK-I3 |  | 0.00
AO | 6 | 6 | 0 | 0 | U10,U15 | LM358 | 0.35 | 2.13
Diodes | 12 | 10 | 2 | 0 | D10-D13 | DIODE | 1.90 | 19.00
Potentiomètre | 3 | 3 | 0 | 0 | POT1 | 30k | 0.60 | 1.80
Potentiomètre | 6 | 6 | 0 | 0 | POT10-POT11 | 10k | 0.60 | 3.60
Emetteur US | 7 | 7 | 0 | 0 | X0-X2 | Emetteur | 3.50 | 24.50
Recepteur US | 6 | 6 | 0 | 0 | X10-X11 | Recepteur | 4.50 | 27.00
Support | 2 | 0 | 2 | 0 | dil aop | 8 |  | 0.00
Support | 3 | 0 | 3 | 0 | dil non | 16 |  | 0.00
Support | 3 | 0 | 3 | 0 | dil nand | 14 |  | 0.00
Support | 4 | 0 | 0 | 4 | header | 30 | 0.54 | 0.00
Support | 4 | 0 | 1 | 3 | header hf | 8 |  | 0.00
Switch | 9 | 9 | 0 | 0 | monostable |  | 0.11 | 0.99
LED RGB | 3 | 0 | 3 | 0 |  |  |  | 0.00
arduino nano | 4 | 4 | 0 | 0 |  |  | 2.32 | 9.28
Module NRF | 3 | 3 | 0 | 0 | 2,4 Ghz |  | 1.93 | 5.80
Vis | 25 | 25 | 0 | 0 | FHC M3 30 |  | 0.132 | 3.30
 |  |  |  |  |  |  | Total | 107.95

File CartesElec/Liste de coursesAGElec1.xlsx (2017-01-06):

Bill Of Materials for
Design Title
Author |  | Bruno Bellier
Document Number
Revision |  | 1
Design Created |  | jeudi 17 septembre 2015
Design Last Modified |  | vendredi 9 octobre 2015
Total Parts In Design |  | 141
 |  |  |  |  |  |  | Totals
Category | Quantity |  | References | Value | PrixUnitaire | Prix | Category | Quantity
Condensateurs | 3 | 3 | C0 | 560pF | 0.30 | 0.90 | Condensateurs | 38
Condensateurs | 4 | 0 | C1,C18 | 330nF |  | 0.00 | Resistors | 51
Condensateurs | 7 | 0 | C2-C3,C19 | 100nF |  | 0.00 | Integrated Circuits | 18
Condensateurs | 12 | 8 | C10-C11,C14-C15 | 10nF | 0.30 | 2.40 | Diodes | 12
Condensateurs | 12 | 5 | C12-C13,C16-C17 | 1nF | 0.30 | 1.50 | Miscellaneous | 22
Resistors | 27 | 24 | R0,R10,R12-R14,R18,R20-R22 | 100k | 0.10 | 2.40 | Total | 141
Resistors | 6 | 5 | R11,R19 | 1k | 0.10 | 0.50
Resistors | 6 | 0 | R15,R23 | 3.9k |  | 0.00
Resistors | 6 | 0 | R16,R24 | 10k |  | 0.00
Resistors | 6 | 0 | R17,R25 | 6M |  | 0.00
Integrated Circuits | 3 | 3 | U0 | 4049 | 0.95 | 2.85
Integrated Circuits | 5 | 0 | U1,U13-U14 | 7410 |  | 0.00
Integrated Circuits |  | 0 | U2,U11 | TBLOCK-I3 |  | 0.00
Integrated Circuits | 4 | 0 | U3,U12 | 7805 |  | 0.00
Integrated Circuits | 6 | 0 | U10,U15 | LM358 |  | 0.00
Diodes | 12 | 10 | D10-D13 | DIODE | 1.90 | 19.00
Miscellaneous | 3 | 3 | POT1 | 30k | 0.60 | 1.80
Miscellaneous | 6 | 6 | POT10-POT11 | 10k | 0.60 | 3.60
Miscellaneous | 7 | 7 | X0-X2 | Emetteur | 3.50 | 24.50
Miscellaneous | 6 | 6 | X10-X11 | Recepteur | 4.50 | 27.00
 |  |  |  |  | Total | 86.45

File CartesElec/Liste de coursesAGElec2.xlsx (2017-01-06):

Bill Of Materials for Balises
Design Title |  |  | Balises
Author
Document Number
Revision
Design Created |  |  | jeudi 17 septembre 2015
Design Last Modified |  |  | jeudi 17 décembre 2015
Total Parts In Design |  |  | 48
 |  |  |  |  | Totals
Category | Quantity | References | Value | manque | Category | Quantity
Condensateurs | 7 | C1,C11-C16 | 1nF | 0 | Condensateurs | 12
Condensateurs | 1 | C2 | 10nF | 0 | Resistors | 20
Condensateurs | 3 | C3,C5,C9 | 100nF | 0 | Integrated Circuits | 2
Condensateurs | 1 | C4 | 47µF | 0 | Diodes | 1
Resistors | 1 | R1 | 22k | 0 | Miscellaneous | 13
Resistors | 4 | R2,R6-R8 | 100k | 0 | Total | 48
Resistors | 2 | R3,R5 | 10k | 0
Resistors | 1 | R4 | 1M | 0
Resistors | 6 | R11-R16 | 1k | 0
Resistors | 6 | R21-R26 | 3.9K | 2
Miscellaneous | 1 |  | 4049 | 1
Miscellaneous | 1 | S1 | switch? | 0
Miscellaneous | 6 | X1-X6 | CRYSTAL | 0
PILE |  | 9V |  | 4
connecteur pile |  |  |  | 0

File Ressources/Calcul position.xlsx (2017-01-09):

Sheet: Feuil1
x | 100.0 | cm | Entrées des calculs
y | 150.0 | cm
d1 | 180.3 | cm
d2 | 111.8 | cm
d3 | 206.2 | cm
d1 | 180.3 | cm
d2 | 111.8 | cm
d3 | 206.2 | cm
x | 100.0 | cm
y | 150.0 | cm

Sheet: Feuil2
Index | t | x_1 | Fixe1 | x_2 | Fixe2 | x_3 | Fixe3 | x_T | Table | balise fixes en cm
0 | 0 | 180.3 | 0 | 111.8 | 200 | 506.2 | 100 | 0 | 0 | x_1 | y_1 | x_2 | y_2 | x_3 | y_3 | t min | tmax | pas | NbPoints
1 | 0.06283185307 | 179.9442191 | 11.32113067 | 111.5793882 | 207.0199801 | 505.7931114 | 112.9474051 | 0 | 200 | 0 | 0 | 0 | 200 | 300 | 100 | 0 | 6.283185307 | 0.06283185307 | 100
2 | 0.1256637061 | 178.8782806 | 22.59758201 | 110.9184236 | 214.0122555 | 504.5740514 | 125.8437128 | 0 | 200
3 | 0.1884955592 | 177.1063913 | 33.78485102 | 109.8197146 | 220.949231 | 502.5476311 | 138.6380271 | 0 | 200
4 | 0.2513274123 | 174.635544 | 44.83878666 | 108.2875974 | 227.8035294 | 499.7218478 | 151.2798547 | 0 | 200
5 | 0.3141592654 | 171.4754899 | 55.71576409 | 106.3281185 | 234.5481 | 496.1078537 | 163.7193042 | 0 | 200
6 | 0.3769911184 | 167.6387004 | 66.37285685 | 103.9490111 | 241.156325 | 491.7199114 | 175.9072828 | 0 | 200
7 | 0.4398229715 | 163.1403176 | 76.76800627 | 101.1596645 | 247.6021248 | 486.5753382 | 187.7956899 | 0 | 200
8 | 0.5026548246 | 157.9980944 | 86.86018744 | 97.97108683 | 253.8600608 | 480.6944374 | 199.3376076 | 0 | 200
9 | 0.5654866776 | 152.232325 | 96.60957113 | 94.39586207 | 259.9054357 | 474.1004182 | 210.4874851 | 0 | 200
10 | 0.6283185307 | 145.8657641 | 105.977681 | 90.44809997 | 265.7143912 | 466.8193042 | 221.201319 | 0 | 200
11 | 0.6911503838 | 138.9235377 | 114.9275454 | 86.14338054 | 271.2640021 | 458.8798307 | 231.4368267 | 0 | 200
12 | 0.7539822369 | 131.4330435 | 123.4238432 | 81.49869255 | 276.5323664 | 450.313331 | 241.1536132 | 0 | 200
13 | 0.8168140899 | 123.4238432 | 131.4330435 | 76.53236644 | 281.4986925 | 441.1536132 | 250.313331 | 0 | 200
14 | 0.879645943 | 114.9275454 | 138.9235377 | 71.26400205 | 286.1433805 | 431.4368267 | 258.8798307 | 0 | 200
15 | 0.9424777961 | 105.977681 | 145.8657641 | 65.71439121 | 290.4481 | 421.201319 | 266.8193042 | 0 | 200
16 | 1.005309649 | 96.60957113 | 152.232325 | 59.90543568 | 294.3958621 | 410.4874851 | 274.1004182 | 0 | 200
17 | 1.068141502 | 86.86018744 | 157.9980944 | 53.86006076 | 297.9710868 | 399.3376076 | 280.6944374 | 0 | 200
18 | 1.130973355 | 76.76800627 | 163.1403176 | 47.6021248 | 301.1596645 | 387.7956899 | 286.5753382 | 0 | 200
19 | 1.193805208 | 66.37285685 | 167.6387004 | 41.15632499 | 303.9490111 | 375.9072828 | 291.7199114 | 0 | 200
20 | 1.256637061 | 55.71576409 | 171.4754899 | 34.54809997 | 306.3281185 | 363.7193042 | 296.1078537 | 0 | 200
21 | 1.319468915 | 44.83878666 | 174.635544 | 27.80352939 | 308.2875974 | 351.2798547 | 299.7218478 | 300 | 200
22 | 1.382300768 | 33.78485102 | 177.1063913 | 20.94923097 | 309.8197146 | 338.6380271 | 302.5476311 | 300 | 200
23 | 1.445132621 | 22.59758201 | 178.8782806 | 14.01225551 | 310.9184236 | 325.8437128 | 304.5740514 | 300 | 200
24 | 1.507964474 | 11.32113067 | 179.9442191 | 7.019980083 | 311.5793882 | 312.9474051 | 305.7931114 | 300 | 200
25 | 1.570796327 | -2.898992895e-14 | 180.3 | -1.797600697e-14 | 311.8 | 300 | 306.2 | 300 | 200
26 | 1.63362818 | -11.32113067 | 179.9442191 | -7.019980083 | 311.5793882 | 287.0525949 | 305.7931114 | 300 | 200
27 | 1.696460033 | -22.59758201 | 178.8782806 | -14.01225551 | 310.9184236 | 274.1562872 | 304.5740514 | 300 | 200
28 | 1.759291886 | -33.78485102 | 177.1063913 | -20.94923097 | 309.8197146 | 261.3619729 | 302.5476311 | 300 | 200
29 | 1.822123739 | -44.83878666 | 174.635544 | -27.80352939 | 308.2875974 | 248.7201453 | 299.7218478 | 300 | 200
30 | 1.884955592 | -55.71576409 | 171.4754899 | -34.54809997 | 306.3281185 | 236.2806958 | 296.1078537 | 300 | 200
31 | 1.947787445 | -66.37285685 | 167.6387004 | -41.15632499 | 303.9490111 | 224.0927172 | 291.7199114 | 300 | 200
32 | 2.010619298 | -76.76800627 | 163.1403176 | -47.6021248 | 301.1596645 | 212.2043101 | 286.5753382 | 300 | 200
33 | 2.073451151 | -86.86018744 | 157.9980944 | -53.86006076 | 297.9710868 | 200.6623924 | 280.6944374 | 300 | 200
34 | 2.136283004 | -96.60957113 | 152.232325 | -59.90543568 | 294.3958621 | 189.5125149 | 274.1004182 | 300 | 200
35 | 2.199114858 | -105.977681 | 145.8657641 | -65.71439121 | 290.4481 | 178.798681 | 266.8193042 | 300 | 200
36 | 2.261946711 | -114.9275454 | 138.9235377 | -71.26400205 | 286.1433805 | 168.5631733 | 258.8798307 | 300 | 200
37 | 2.324778564 | -123.4238432 | 131.4330435 | -76.53236644 | 281.4986925 | 158.8463868 | 250.313331 | 300 | 200
38 | 2.387610417 | -131.4330435 | 123.4238432 | -81.49869255 | 276.5323664 | 149.686669 | 241.1536132 | 300 | 200
39 | 2.45044227 | -138.9235377 | 114.9275454 | -86.14338054 | 271.2640021 | 141.1201693 | 231.4368267 | 300 | 200
40 | 2.513274123 | -145.8657641 | 105.977681 | -90.44809997 | 265.7143912 | 133.1806958 | 221.201319 | 300 | 200
41 | 2.576105976 | -152.232325 | 96.60957113 | -94.39586207 | 259.9054357 | 125.8995818 | 210.4874851 | 300 | 200
42 | 2.638937829 | -157.9980944 | 86.86018744 | -97.97108683 | 253.8600608 | 119.3055626 | 199.3376076 | 300 | 200
43 | 2.701769682 | -163.1403176 | 76.76800627 | -101.1596645 | 247.6021248 | 113.4246618 | 187.7956899 | 300 | 200
44 | 2.764601535 | -167.6387004 | 66.37285685 | -103.9490111 | 241.156325 | 108.2800886 | 175.9072828 | 300 | 200
45 | 2.827433388 | -171.4754899 | 55.71576409 | -106.3281185 | 234.5481 | 103.8921463 | 163.7193042 | 300 | 200
46 | 2.890265241 | -174.635544 | 44.83878666 | -108.2875974 | 227.8035294 | 100.2781522 | 151.2798547 | 300 | 200
47 | 2.953097094 | -177.1063913 | 33.78485102 | -109.8197146 | 220.949231 | 97.4523689 | 138.6380271 | 300 | 200
48 | 3.015928947 | -178.8782806 | 22.59758201 | -110.9184236 | 214.0122555 | 95.42594859 | 125.8437128 | 300 | 200
49 | 3.078760801 | -179.9442191 | 11.32113067 | -111.5793882 | 207.0199801 | 94.2068886 | 112.9474051 | 300 | 200
50 | 3.141592654 | -180.3 | -5.797985789e-14 | -111.8 | 200 | 93.8 | 100 | 300 | 200
51 | 3.204424507 | -179.9442191 | -11.32113067 | -111.5793882 | 192.9800199 | 94.2068886 | 87.05259487 | 300 | 0
52 | 3.26725636 | -178.8782806 | -22.59758201 | -110.9184236 | 185.9877445 | 95.42594859 | 74.15628724 | 300 | 0
53 | 3.330088213 | -177.1063913 | -33.78485102 | -109.8197146 | 179.050769 | 97.4523689 | 61.36197293 | 300 | 0
54 | 3.392920066 | -174.635544 | -44.83878666 | -108.2875974 | 172.1964706 | 100.2781522 | 48.72014527 | 300 | 0
55 | 3.455751919 | -171.4754899 | -55.71576409 | -106.3281185 | 165.4519 | 103.8921463 | 36.28069576 | 300 | 0
56 | 3.518583772 | -167.6387004 | -66.37285685 | -103.9490111 | 158.843675 | 108.2800886 | 24.09271724 | 300 | 0
57 | 3.581415625 | -163.1403176 | -76.76800627 | -101.1596645 | 152.3978752 | 113.4246618 | 12.20431008 | 300 | 0
58 | 3.644247478 | -157.9980944 | -86.86018744 | -97.97108683 | 146.1399392 | 119.3055626 | 0.6623924002 | 300 | 0
59 | 3.707079331 | -152.232325 | -96.60957113 | -94.39586207 | 140.0945643 | 125.8995818 | -10.48748512 | 300 | 0
60 | 3.769911184 | -145.8657641 | -105.977681 | -90.44809997 | 134.2856088 | 133.1806958 | -21.20131902 | 300 | 0
61 | 3.832743037 | -138.9235377 | -114.9275454 | -86.14338054 | 128.7359979 | 141.1201693 | -31.43682669 | 300 | 0
62 | 3.89557489 | -131.4330435 | -123.4238432 | -81.49869255 | 123.4676336 | 149.686669 | -41.15361324 | 300 | 0
63 | 3.958406744 | -123.4238432 | -131.4330435 | -76.53236644 | 118.5013075 | 158.8463868 | -50.31333097 | 300 | 0
64 | 4.021238597 | -114.9275454 | -138.9235377 | -71.26400205 | 113.8566195 | 168.5631733 | -58.87983066 | 300 | 0
65 | 4.08407045 | -105.977681 | -145.8657641 | -65.71439121 | 109.5519 | 178.798681 | -66.81930424 | 300 | 0
66 | 4.146902303 | -96.60957113 | -152.232325 | -59.90543568 | 105.6041379 | 189.5125149 | -74.10041824 | 300 | 0
67 | 4.209734156 | -86.86018744 | -157.9980944 | -53.86006076 | 102.0289132 | 200.6623924 | -80.69443743 | 300 | 0
68 | 4.272566009 | -76.76800627 | -163.1403176 | -47.6021248 | 98.84033553 | 212.2043101 | -86.57533822 | 300 | 0
69 | 4.335397862 | -66.37285685 | -167.6387004 | -41.15632499 | 96.05098888 | 224.0927172 | -91.71991139 | 300 | 0
70 | 4.398229715 | -55.71576409 | -171.4754899 | -34.54809997 | 93.67188148 | 236.2806958 | -96.10785366 | 300 | 0
71 | 4.461061568 | -44.83878666 | -174.635544 | -27.80352939 | 91.71240259 | 248.7201453 | -99.72184782 | 0 | 0
72 | 4.523893421 | -33.78485102 | -177.1063913 | -20.94923097 | 90.18028537 | 261.3619729 | -102.5476311 | 0 | 0
73 | 4.586725274 | -22.59758201 | -178.8782806 | -14.01225551 | 89.08157639 | 274.1562872 | -104.5740514 | 0 | 0
74 | 4.649557127 | -11.32113067 | -179.9442191 | -7.019980083 | 88.42061176 | 287.0525949 | -105.7931114 | 0 | 0
75 | 4.71238898 | -3.313413996e-14 | -180.3 | -2.054573959e-14 | 88.2 | 300 | -106.2 | 0 | 0
76 | 4.775220833 | 11.32113067 | -179.9442191 | 7.019980083 | 88.42061176 | 312.9474051 | -105.7931114 | 0 | 0
77 | 4.838052687 | 22.59758201 | -178.8782806 | 14.01225551 | 89.08157639 | 325.8437128 | -104.5740514 | 0 | 0
78 | 4.90088454 | 33.78485102 | -177.1063913 | 20.94923097 | 90.18028537 | 338.6380271 | -102.5476311 | 0 | 0
79 | 4.963716393 | 44.83878666 | -174.635544 | 27.80352939 | 91.71240259 | 351.2798547 | -99.72184782 | 0 | 0
80 | 5.026548246 | 55.71576409 | -171.4754899 | 34.54809997 | 93.67188148 | 363.7193042 | -96.10785366 | 0 | 0
81 | 5.089380099 | 66.37285685 | -167.6387004 | 41.15632499 | 96.05098888 | 375.9072828 | -91.71991139 | 0 | 0
82 | 5.152211952 | 76.76800627 | -163.1403176 | 47.6021248 | 98.84033553 | 387.7956899 | -86.57533822 | 0 | 0
83 | 5.215043805 | 86.86018744 | -157.9980944 | 53.86006076 | 102.0289132 | 399.3376076 | -80.69443743 | 0 | 0
84 | 5.277875658 | 96.60957113 | -152.232325 | 59.90543568 | 105.6041379 | 410.4874851 | -74.10041824 | 0 | 0
85 | 5.340707511 | 105.977681 | -145.8657641 | 65.71439121 | 109.5519 | 421.201319 | -66.81930424 | 0 | 0
86 | 5.403539364 | 114.9275454 | -138.9235377 | 71.26400205 | 113.8566195 | 431.4368267 | -58.87983066 | 0 | 0
87 | 5.466371217 | 123.4238432 | -131.4330435 | 76.53236644 | 118.5013075 | 441.1536132 | -50.31333097 | 0 | 0
88 | 5.52920307 | 131.4330435 | -123.4238432 | 81.49869255 | 123.4676336 | 450.313331 | -41.15361324 | 0 | 0
89 | 5.592034923 | 138.9235377 | -114.9275454 | 86.14338054 | 128.7359979 | 458.8798307 | -31.43682669 | 0 | 0
90 | 5.654866776 | 145.8657641 | -105.977681 | 90.44809997 | 134.2856088 | 466.8193042 | -21.20131902 | 0 | 0
91 | 5.71769863 | 152.232325 | -96.60957113 | 94.39586207 | 140.0945643 | 474.1004182 | -10.48748512 | 0 | 0
92 | 5.780530483 | 157.9980944 | -86.86018744 | 97.97108683 | 146.1399392 | 480.6944374 | 0.6623924002 | 0 | 0
93 | 5.843362336 | 163.1403176 | -76.76800627 | 101.1596645 | 152.3978752 | 486.5753382 | 12.20431008 | 0 | 0
94 | 5.906194189 | 167.6387004 | -66.37285685 | 103.9490111 | 158.843675 | 491.7199114 | 24.09271724 | 0 | 0
95 | 5.969026042 | 171.4754899 | -55.71576409 | 106.3281185 | 165.4519 | 496.1078537 | 36.28069576 | 0 | 0
96 | 6.031857895 | 174.635544 | -44.83878666 | 108.2875974 | 172.1964706 | 499.7218478 | 48.72014527 | 0 | 0
97 | 6.094689748 | 177.1063913 | -33.78485102 | 109.8197146 | 179.050769 | 502.5476311 | 61.36197293 | 0 | 0
98 | 6.157521601 | 178.8782806 | -22.59758201 | 110.9184236 | 185.9877445 | 504.5740514 | 74.15628724 | 0 | 0
99 | 6.220353454 | 179.9442191 | -11.32113067 | 111.5793882 | 192.9800199 | 505.7931114 | 87.05259487 | 0 | 0
100 | 6.283185307 | 180.3 | 1.159597158e-13 | 111.8 | 200 | 506.2 | 100 | 0 | 0

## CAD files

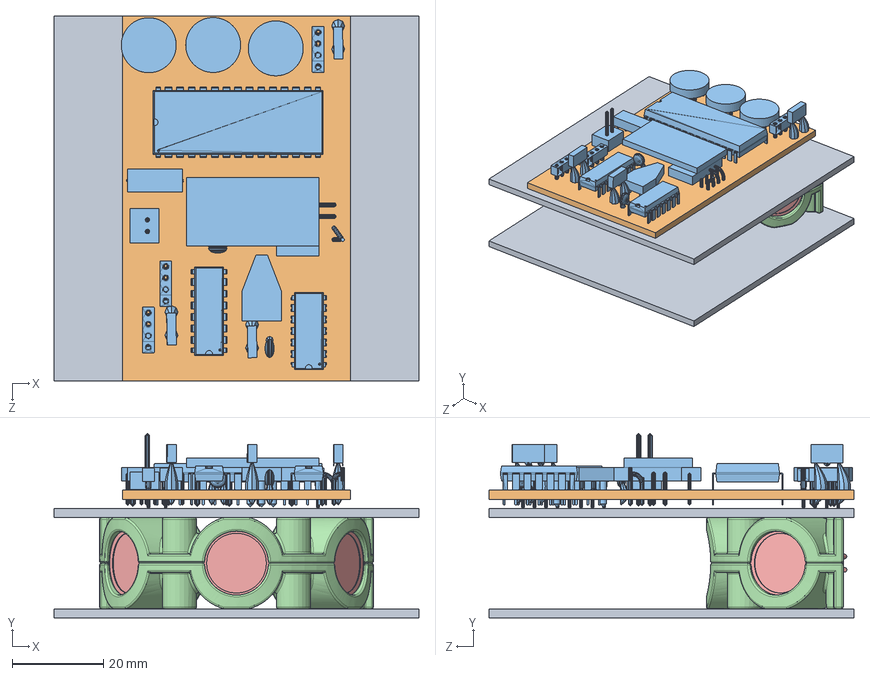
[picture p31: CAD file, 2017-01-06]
CAO_SupportUltra-son/Balise emettrice 180.SLDASM
80.0 x 40.5 x 80.0 mm
plaque socle x 2
plaque Cicuit
circuitE
Support 180 x 2
Recepteur_Emetteur x 3

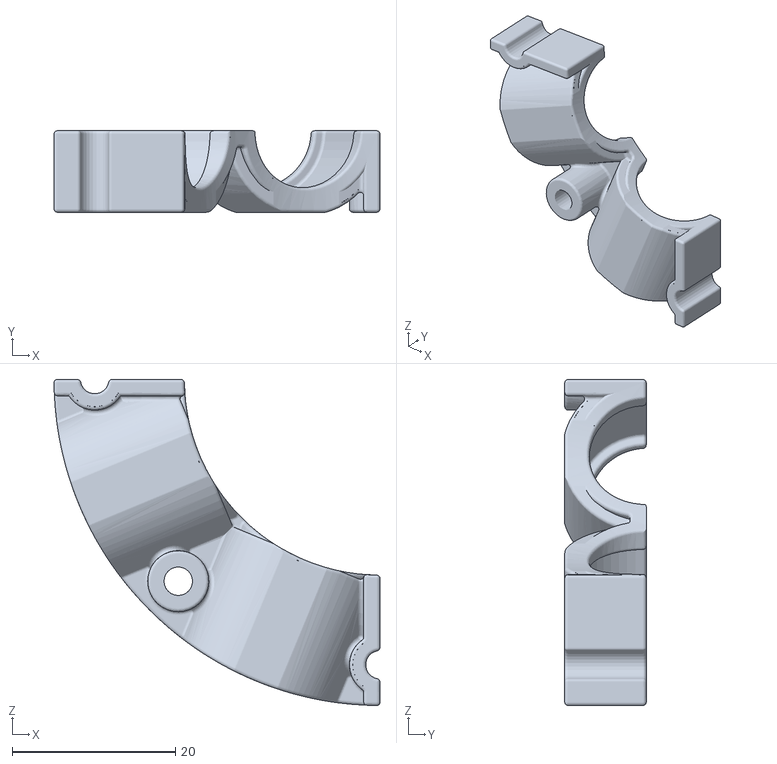
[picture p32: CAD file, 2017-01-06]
CAO_SupportUltra-son/PourImpression3D/Support 90.STL
40.0 x 10.00 x 40.0

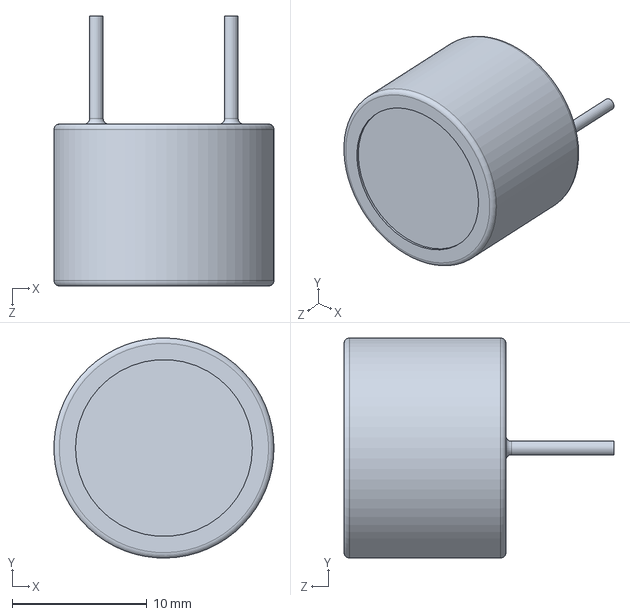
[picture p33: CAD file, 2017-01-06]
CAO_SupportUltra-son/Recepteur_Emetteur.SLDPRT
16.3 x 16.3 x 20.0 mm

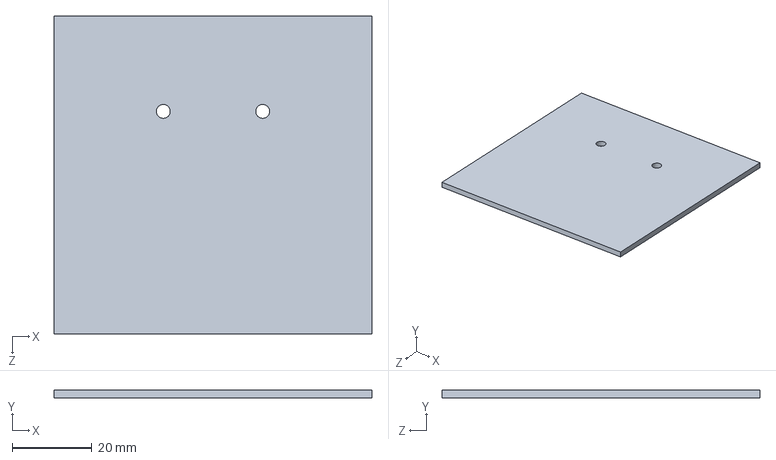
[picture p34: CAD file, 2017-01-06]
CAO_SupportUltra-son/plaque socle.SLDPRT
80.0 x 2.00 x 80.0 mm

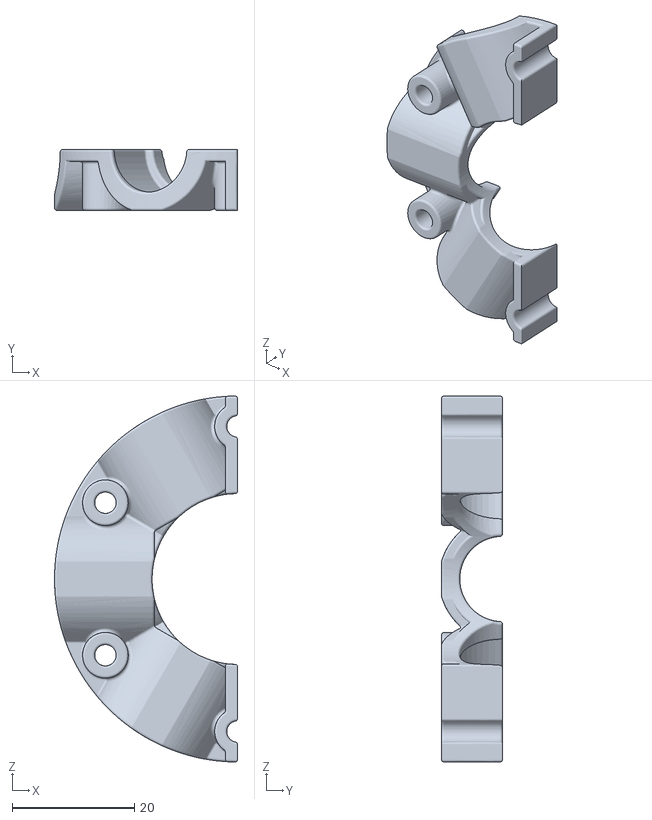
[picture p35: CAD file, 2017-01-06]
CAO_SupportUltra-son/PourImpression3D/Support 180.STL
30.0 x 10.00 x 60.0

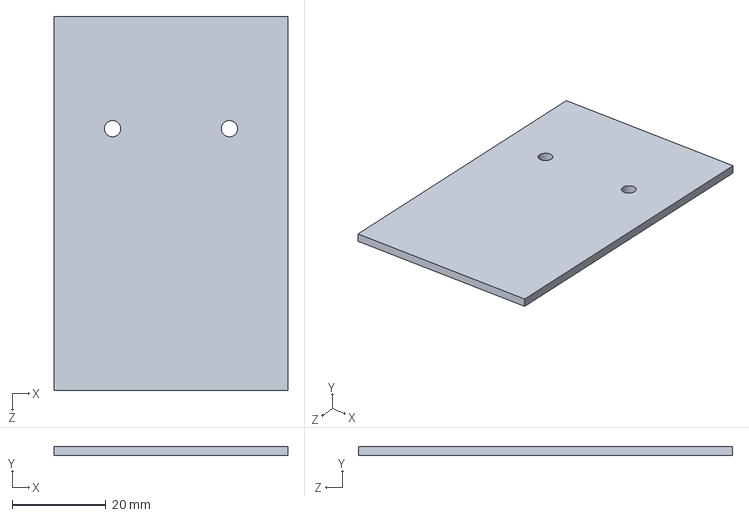
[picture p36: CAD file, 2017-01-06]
CAO_SupportUltra-son/plaque Cicuit.SLDPRT
50.0 x 2.00 x 80.0 mm

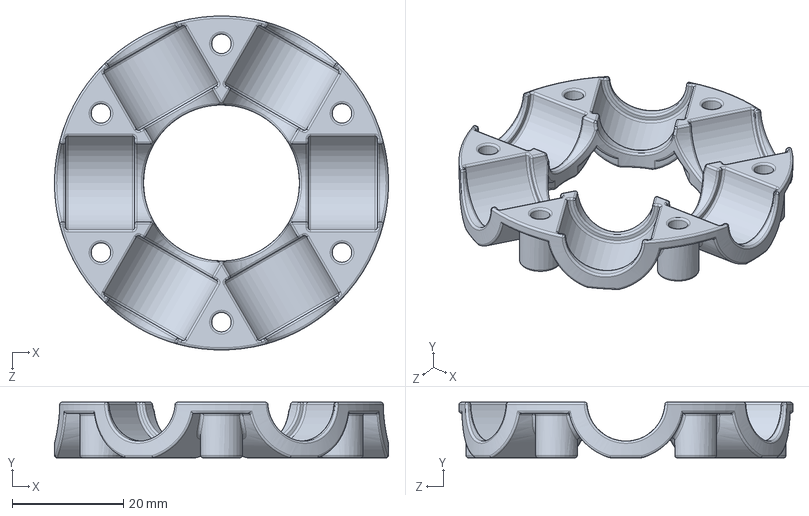
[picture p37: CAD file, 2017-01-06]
CAO_SupportUltra-son/Support 360.SLDPRT
60.0 x 10.0 x 60.0 mm

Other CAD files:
CAO_SupportUltra-son/Support.SLDPRT
CAO_SupportUltra-son/Support 180.SLDPRT
CAO_SupportUltra-son/Support 90.SLDPRT
CAO_SupportUltra-son/Support.STL

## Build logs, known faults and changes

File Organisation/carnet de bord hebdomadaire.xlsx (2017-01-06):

semaine | action effectuée | action programmée
2015-09-10 | création du cahier des charges;étape creativité (spider, inverse); ressort plusieurs idée (infrarouge, ultrason, analyse d'image); recherche doc et choix méthode localisation (type GPS)
2015-09-17 | Recherche doc comparaison infrarouge/ultrason; choix de l'ultrason car on pense que c'est le moins utilisé; récupération de datasheet d'émetteur et recepteur ultrason avec analyse des circuit exemple; reprendre l'idée de comparer la variation de temps entre onde HF (lumineuse) et onde sonique; tester les montages exemples:Pour la phase de conception electronique, nous avons trouvé la data sheet des émetteur-récepteur que le club possede. Ce qui nous a donner un modèle, nous avons ensuite construit le circuit fonction par fonction pour les tester au fur et à mesure. en premier lieu, le générateur de 40kHz en 0-10v puis la double amplitude centrée, -10v;10v. Après nous avons construit le circuit de réception avec un ao en non-inverseur. sur l'entrée, il y a la fonction ommateur, la ainsi qu'un lissage des pic. Le signal ce vois donc osciller, centrée sur le (5V).
2015-09-24 | Avec les succès des ces deux parties la liaison ultrason est assurée. Mais le signal reçu n'est pas exploitable. Des tests on montrer que seul une comparaison ne suffit pas donc en examinant un shema plus complet de la datasheet, nous avons ajouter en série un condensateur pour centrée le signal sur 0. on a rajouter une diode en parallele avec la masse, puis une en série, pour couper la partie négative. c'est mieux mais à cause du temps de réaction des ao, quand le récepteur est trop près il y a saturation complète : le mot n'est pas reçu. Test modulation de la porteuse avec arduino avec sortie série; recherche de protocole de communication en bus unifilaire et choix d'un brevet jouant sur la durée de l'état haut; codage du protocole sur arduino
2015-10-01 | emetteur et recepteur codés sur arduino; probleme de communication en n'utilisant qu'un fil (sans emetteur/recepeteur ultrason); probleme venant de l'utilisation du port série pour emettre donc application du protocole sur pin classique; transmission d'info reussi a etre sur, mais probleme de temps entre deux message compris; Transmission message par fil reussi à plus de 80%; Problème rencontré sur la reconnaissance de front fourni par circuit recepteur à l'arduino; Communication etablie une communication entre arduino avec emetteur/recepteur HF.
2015-10-08 | Travail sur le seuil de référence pour traitement message US. Essay avec trigger de schmit, pas vraiment concluant. Discussion avec Jouve qui nous a expliquer nos magouilles. Ajout capa en série avec la masse en conservant la résistance (mais descendu à 1Mohm). Reussite communication US à 100%, mais si programme surchargé. Assemblage des deux communication et retravaille afin d'obtenir des réponse, mais résultat faux. Refonte complète du programme réception US.
2015-10-15 | Test et correction du programme US, jusqu'à taux de réussite de 100%. Réinsertion dans le programme assemblé et réussite de reception complète. Problème de calcul de distance et de temps oscillant. Passage du calcul de temps de la millis a la micros. Temps de transmission mesuré stable, mais erreur statique de calcul de distance importante:grosse d'erreur. Ajustement du délais avant de décider que trop long, permit d'avoir temps mesuré toujours stable, meme après interruption. Etalonnage erreur statique sur excel avec obtention equation linéaire. Analyse librairie HF. Discution sur le projet ECAM 2025 avec Capucine. Modification .h et réussite a faire un broadcast en HF. Recherche des piles. Recherche arduino en mode radin. Conception des cartes des circuit emetteur et recepteur et conception sur solidworks.
2015-10-23 | Validation du circuit et adaptation selon Jouve.modification circuit pour intégré selecteur et afficheur de nom pour les fix, pieuvre et cdcF. Modification des pièces pour impression 3D.
2015-11-06 | Réorganisation du code. Réalisation des circuit imprimé et soudage des composants sur les cartes. Pièce donné à l'impression 3D. Inventaire composants nécessaire pour la réalisation des cartes. Achat de composant manquant. Tests carte émettrice.
2015-12-03 | plage de fréquence ateingnable parle generateur de fréquence: 16kHz-150kHz
2015-12-10 | La balise fonctionne aléatoirement, nous essayons d'autres solution pour faire le circuit recepeteur, nous avons vu y. marchesse qui n'a pas les outils pour faire des mesures de puissance acoustique il nous conseil donc de faire une cartgraphie de la puissance recu par rapport a l'angle et la distance
2015-10-17 | Tests nouvelle solution (sommer les tensions d'entrée fournie par les recepteurs) concluent. Réaménagement du circuit autour afin de créer le signal souhaité en entrée d'arduino. Réalisation du circuit et du PCB.

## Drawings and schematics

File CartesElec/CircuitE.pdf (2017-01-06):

U0:A

U0:B

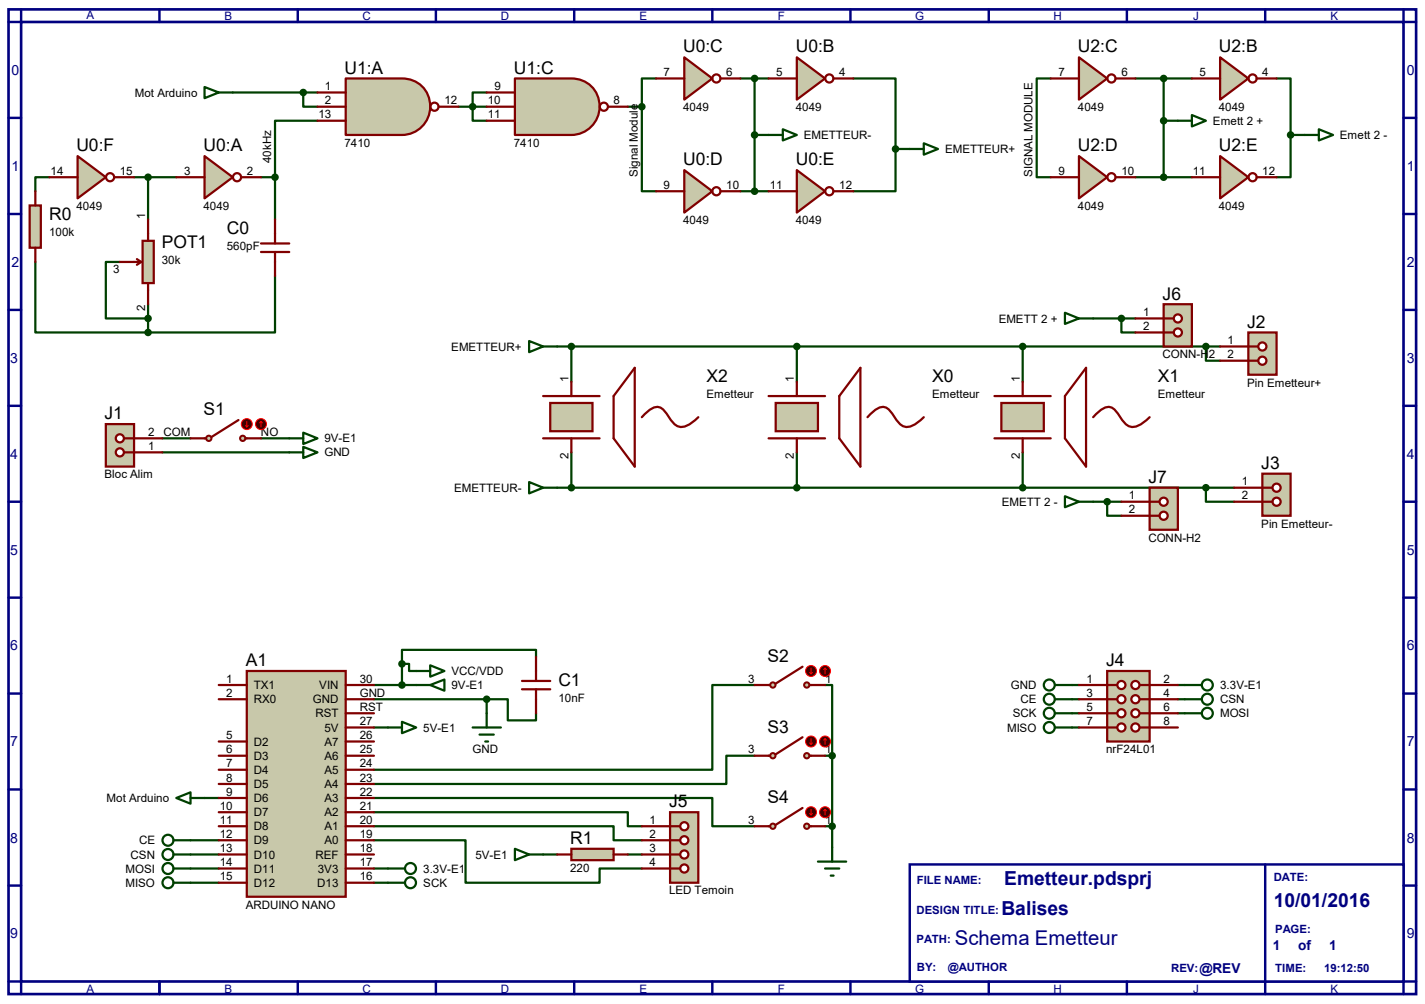
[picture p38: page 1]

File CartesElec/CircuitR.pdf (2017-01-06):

J12

A1

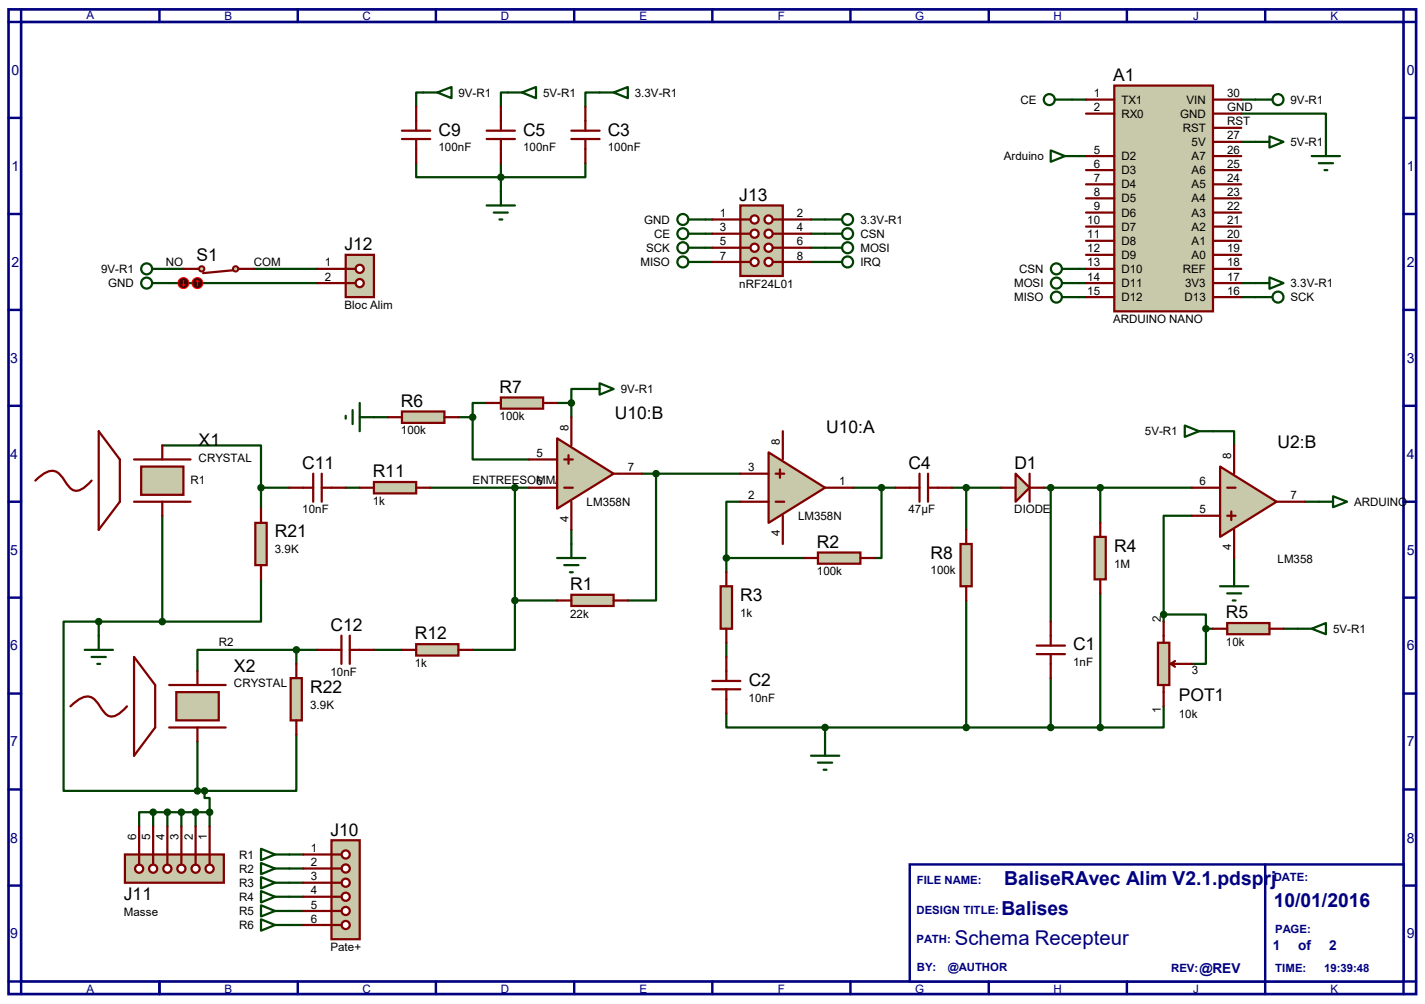
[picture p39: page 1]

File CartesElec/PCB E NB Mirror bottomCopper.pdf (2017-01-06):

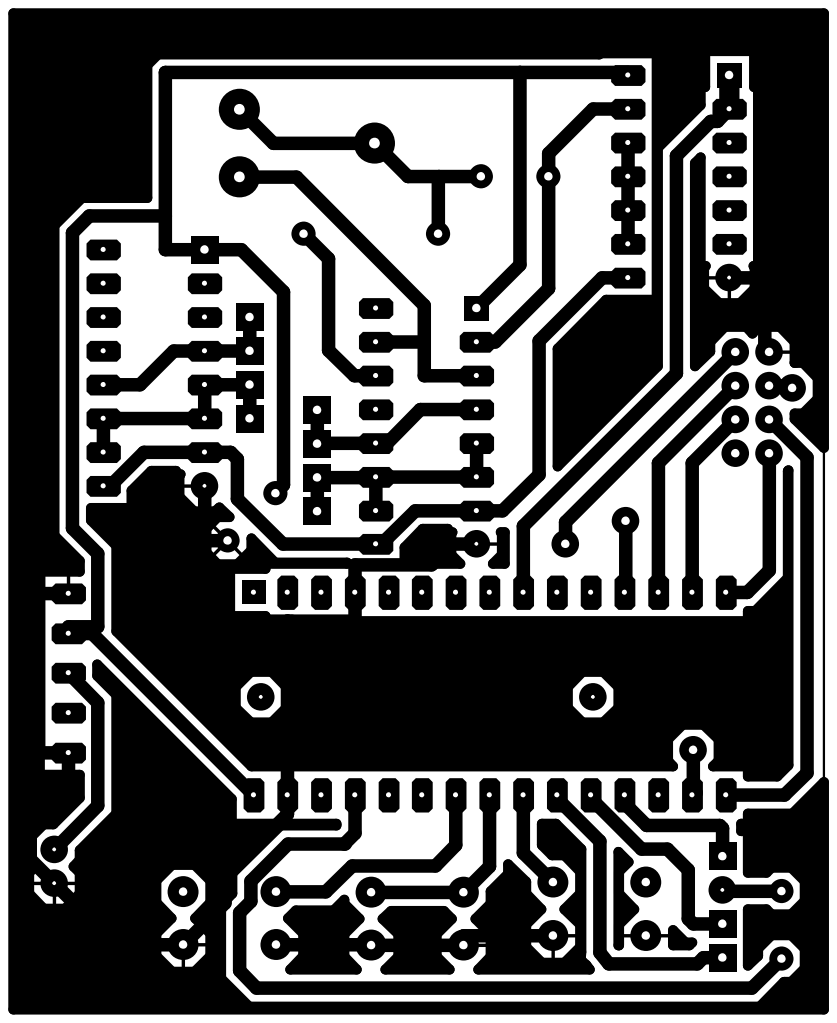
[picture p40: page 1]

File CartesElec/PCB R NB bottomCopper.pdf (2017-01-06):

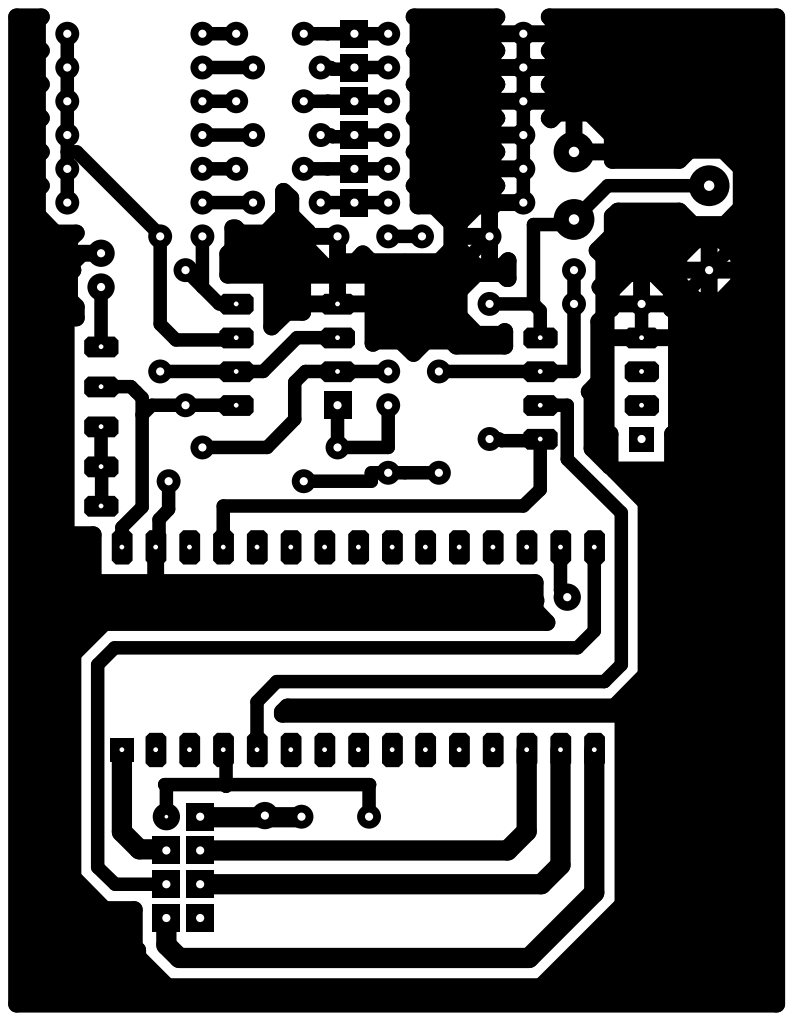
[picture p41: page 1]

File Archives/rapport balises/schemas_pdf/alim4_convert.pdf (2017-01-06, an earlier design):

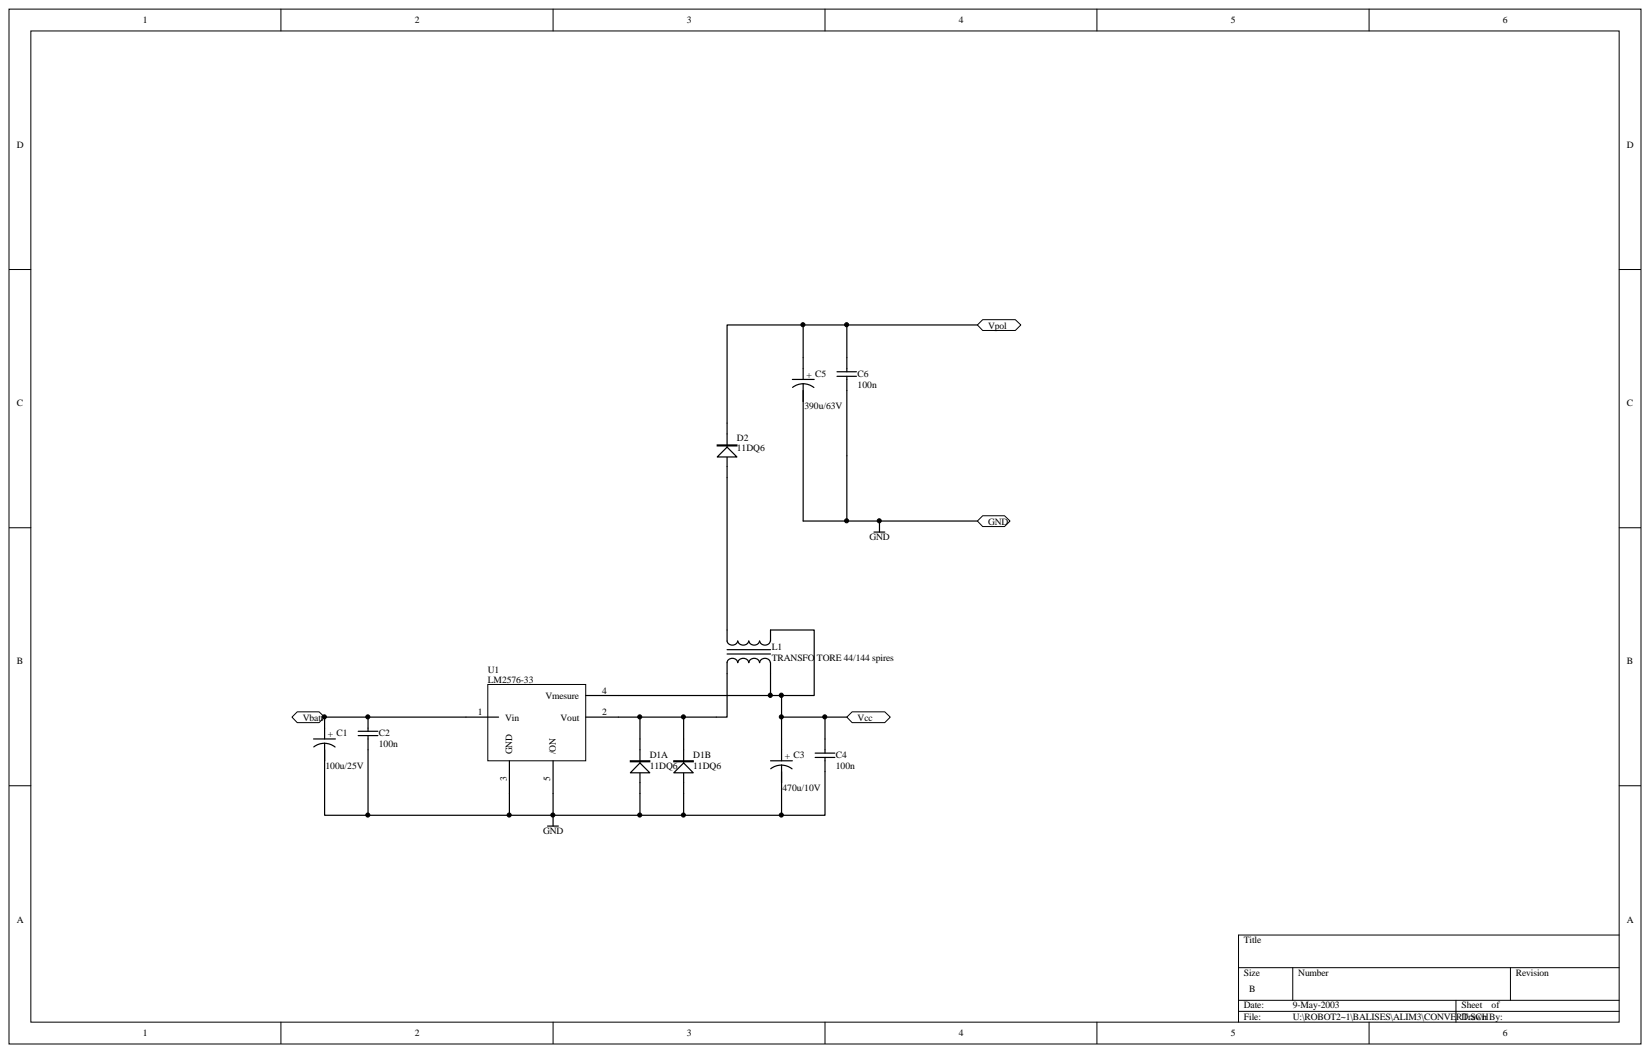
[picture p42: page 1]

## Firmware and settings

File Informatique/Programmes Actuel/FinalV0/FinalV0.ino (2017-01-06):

/* 
  Programme de récéption HF et US 
*/

#include <SPI.h> // gestion du bus SPI 
#include "Const.h"
#include "Methodes.h"

void setup() {
  // put your setup code here, to run once:
  Serial.begin(115200);
  
  // activation interruption
  attachInterrupt(digitalPinToInterrupt(interruptionPin), takeTheTime, FALLING);
  // activation HF
  MirfInit(cePin, csnPin, 2, (byte *)"BFixe", (byte *)"BaliM");
  
  if (debug) Serial.println("Setup done."); 
}

void loop() {
  //
  // Reception HF
  //
  if (debugHF) Serial.println("Listening...");
  long lDebutAttente = millis();
  while(!Mirf.dataReady()) 
  { 
    // pas prêt à recevoir 
    delayMicroseconds(10);  //fonctionne en ne mettant pas de délai mais risque de surcharge
  }
  dateHFRecu=micros();
  Mirf.getData(valeur_octet); // récupére 2 octets 
  valeur = valeur_octet[0] + (valeur_octet[1] << 8); // transforme en int
  if (debugHF) {
    Serial.print("Temps d'attente: "); 
    Serial.print(millis()-lDebutAttente, DEC); 
    Serial.print(" ms.");
    Serial.print(" Valeur recu: ");
    Serial.println(valeur, DEC);
  } 

  //
  // Reception US
  //
  while (i<=nbBits && micros()<(dateHFRecu+300000)) {
    if (dateAnalyse!= 0 && dateAnalyse>derniereDateAnalysee+bitZero){
      noInterrupts();
      analyseUS();
      interrupts();
    }
  }
  if (debugUS) Serial.println(" ");
  if (i>nbBits && donneeRecu==valeur) {
    //Serial.println("Calcul distance");
    calculDistance();
    nettoyage();
    if (tabDistances[0]>2){
      calculPosition();
      //Serial.print("Calcul position");
    }
    
  }else{
    nettoyage();
  }
  
}

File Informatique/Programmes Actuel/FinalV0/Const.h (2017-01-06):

/* 
    réception d’une valeur integer via module nRF24L01 
    Programme de Reception HF uniquement
 *
 * Pins:
 * Hardware SPI:
 * GND             Noir (pin 1)
 * Alim (3.3V)    Rouge (pin 2)
 * MISO -> 50      Vert (pin 7)
 * MOSI -> 51     Jaune (pin 6)
 * SCK -> 52       Bleu (pin 5)
 *
 * Configurable:
 * CE -> 9        Jaune (pin 3)
 * CSN -> 53       Vert (pin 4)
*/

#ifndef _CONST
#define _CONST

#include "Mirf.h" // gestion de la communication 
#include "Mirf_nRF24L01.h" // définition des registres du nRF24L01 
#include "MirfHardwareSpiDriver.h" // communication SPI nRF24L01

// Pins
  const byte cePin = 9;
  const byte csnPin = 10;
  const int interruptionPin=2;// soit 2 soit 3

//Parametres Recepteur US
    const int nbBits=5;         //nb de bits + 1 
    const long iBaseTemps=7000; // en microsecondes
    const long fourchette=7000;
    const long bitStart=iBaseTemps*6-fourchette/2;
    const long bitUn=iBaseTemps*8-fourchette/2;    
    const long bitZero=iBaseTemps*4-fourchette/2;
    const int T=19;
    
    int i=1;
    byte donneeRecu=0x00;
    long dateAnalyse=0;
    long derniereDateAnalysee=0;
    long dateBitStart=0;

// HF
  int valeur = 0;  // contient la valeur à recevoir 
  byte valeur_octet[2]; // contient la valeur découpée en octet pour la réception

  long dateHFRecu;
// Distance mesuree et position

  long tabDistances[]={0,0,0,0};//Un drapeau pour connaitre l'état du tableau + 3 distances
  long tabCoordonnee[]={0,0};

//Parametres Debug
  long DebutDeMot=0;
  bool etatPin=0;
  int OscilloPin=8;
  bool debug = false;
  bool debugHF = false;
  bool debugUS = false;
  bool bProcessing = true;
//Fin Debug



#endif /* _CONST */

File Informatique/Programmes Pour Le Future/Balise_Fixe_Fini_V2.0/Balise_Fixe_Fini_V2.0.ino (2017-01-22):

/*
 * Ce programme contrôles les balises fixes aussi bien le HF que l'US
 *  Ce programme a été remanié depuis les derniers tests.
 *
 * Objectif:
 *   Optimisation du sérial pour ne pas affecter le programme quand on ne l'utilise pas.
 *   Compréhension facile du code par des commentaires très détaillés
 *   Support pour les explications dans le dossier
 *
 * Si il fonctionne avec les balises (normalement c'est le cas) il est préférable de
 * l'utiliser.
 *
 * Si vous avez des questions contactez-nous:
 *   @auteur Maxence Beroujon
 *   @auteur Bruno Bellier    bru.bellier38@gmail.com
 *
 * Copyright (c) 2016
 *   Vous pouvez en faire ce que vous voulez! Mais surtout assez de ne pas le perdre :p
 *   Ce programme ne peut être responsable d'aucune détérioration matériel.
 *   Pour la distribution, consultez la licence de MIRF :p
 */

#include <SPI.h> // gestion du bus SPI 
#include "GlobalVar.h"
#include "Function.h"

void setup() {
  if (debug) Serial.begin(115200);

  /* Definition LEDs, Boutons et le pin dpour la com US*/
  for (int i = 0; i <= 3; i++) {
    pinMode(ledPin[i], OUTPUT);  // setup leds
    digitalWrite(ledPin[i], HIGH); // setup leds OFF
    pinMode(btnPin[i], INPUT);   // setup bouttons
    digitalWrite(btnPin[i], HIGH); // setup pull-up pour btn
  }
  // Ses deux lignes sont les memes que le for au dessus.
  // C'est plus optimiser a l'execution mais moins facile a comprendre
  // Essayer de comprendre pour comprendre le Print configuartion
  //DDRC = B11000111; // SetBtn as in and Led as out
  //PORTC |= B00111111;// Set pull up resistance et led to high

  pinMode(sortieMotUSPin, OUTPUT);

  /* Différenciation des balises */
  bool btnActive = LOW;
  if (debug) Serial.println("Attente d'un bouton actif");
  while (!btnActive) {
    if (digitalRead(btnPin[0]) == 0) {
      idBalise = 1;
    } else if (digitalRead(btnPin[1]) == 0) {
      idBalise = 2;
    } else if (digitalRead(btnPin[2]) == 0) {
      idBalise = 3;
    }

    // Si un bouton a été détecté definitions des constantes de balise
    if (idBalise != 0) {
      btnActive = HIGH;
      byte idBaliseMoins = idBalise - 1; // initialisation pour éviter 2 modifications
      if (idBalise == 1) {
        idBaliseMoins = 3;
      }
      digitalWrite(ledPin[idBalise - 1], LOW);
      motTransmis = idBalise;
      MirfInit(cePin, csnPin, 2, myAdresses[idBaliseMoins] , myAdresses[idBalise]);
    }
  }
  // Valeur découpée en 2 octets pour l’envoi HF
  valeur_octet[0] = motTransmis & 0xFF;
  valeur_octet[1] = (motTransmis & 0xFF00) >> 8;

  /* Print Configuration */
  if (debug) {
    Serial.println("-------------------- Configuation  --------------------");
    Serial.println("Le PortC a pour direction: Valeur attendue= 11000111 ");
    Serial.println(DDRC, BIN);

    Serial.println("Le PortC est définie a la valeur: Valeur attendue= 00111111");
    Serial.println(PORTC, BIN);

    Serial.print("L'id balise est le: ");
    Serial.println(idBalise);
    Serial.println("------------------ End Configuation  ------------------");
  }
}

void loop() {
  if (debug) Serial.println("Listening...");
  long departAttente = millis();
  long timeout = departAttente + 1500 * idBalise;

  digitalWrite(ledPin[idBalise - 1], LOW); // Led allumée lors de l'écoute
  //Attente du top
  while (!Mirf.dataReady() && millis() < timeout)
  {
    // pas message reçu
    //delayMicroseconds(100);
    delay(1);
  }
  digitalWrite(ledPin[idBalise - 1], HIGH);
  
  if (debug) Serial.print("J'ai attendu ");
  if (debug) Serial.print(millis() - departAttente);
  if (debug) Serial.println(" ms");
  byte tabMotSignalDep[2]; // contient la valeur découpée en octet pour la réception
  Mirf.getData(tabMotSignalDep); // récupére 2 octets obligatoire sinon il ne sont pas effacé
  int valeur;
  if (debug) valeur = tabMotSignalDep[0] + (tabMotSignalDep[1] << 8); // transforme en int
  if (debug) Serial.println(valeur, DEC);

  //Changement et envoie HF à Mobile
  Mirf.setTADDR(myAdresses[0]);
  envoyerDataHF(100);
  if (debug) Serial.print("valeur HF emise: ");
  if (debug) Serial.println(valeur_octet[0] + (valeur_octet[1] << 8), DEC);

  //Attente pour decaler
  delay(25);
  
  //Envoi US
  mProtocoleEmetteur();
  if (debug) Serial.print("valeur US emise: ");
  if (debug) Serial.println(motTransmis, DEC);

  // Attente analyse de reception
  delay (100);

  //Changement et envoie HF au Suivant
  Mirf.setTADDR(myAdresses[motTransmis]);
  envoyerDataHF(100);
}

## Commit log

2017-01-06 Start git
    Début du git afin de pouvoir travailler ensemble
    [Balise emettrice 180.SLDASM, Balise ir émmetrice.brd, Balise ir émmetrice.sch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]
2017-01-09 Rangement
    Suppression et déplacement de fichiers
    [Balise ir émmetrice.brd, Balise ir émmetrice.sch, Base de temps US.xlsx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]
2017-01-22 Ajout du clignotement de la LED lors de l'emission. Le programme du futur fonctionne (au moins pour le Tx/Rx HF)
